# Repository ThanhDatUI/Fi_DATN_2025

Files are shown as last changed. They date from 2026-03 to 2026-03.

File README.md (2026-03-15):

# Thiết Kế Và Phát Triển Mũ Bảo Hiểm IoT  
### Hỗ Trợ Giám Sát An Toàn Giao Thông Và Cảnh Báo Nguy Cơ Tai Nạn
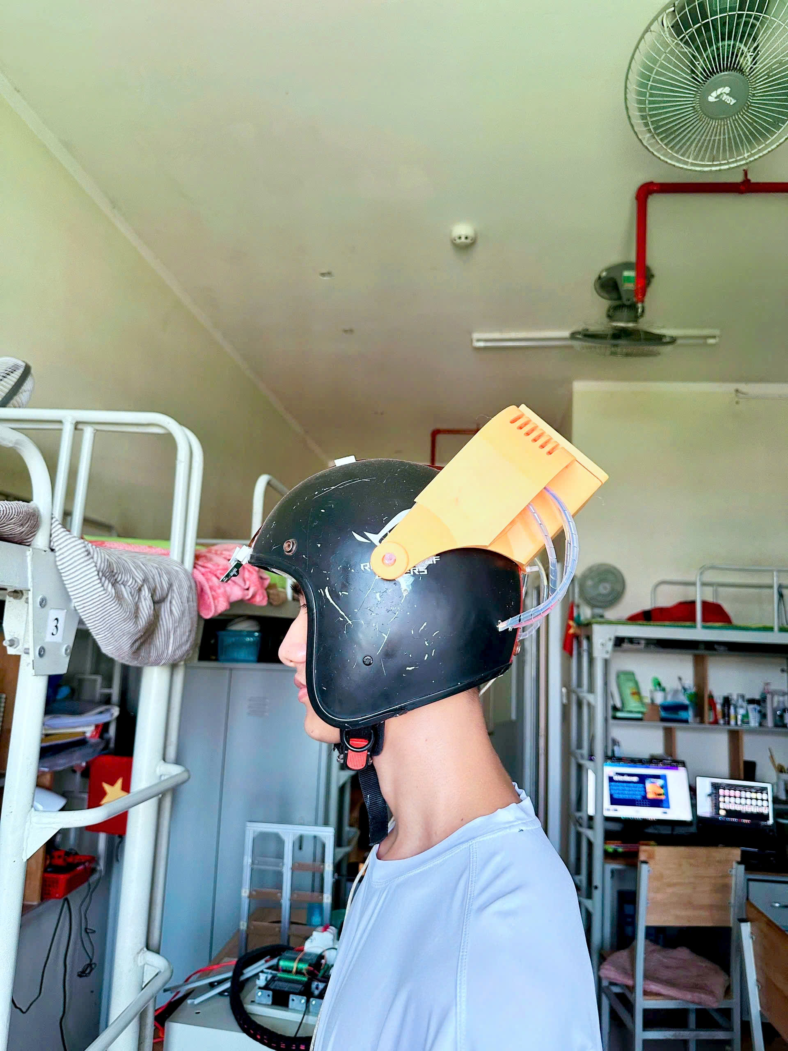
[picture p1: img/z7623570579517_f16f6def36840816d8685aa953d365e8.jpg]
Helmet

## 📌 Giới thiệu
Tai nạn giao thông, đặc biệt liên quan đến xe mô tô, vẫn là vấn đề nghiêm trọng. Nhiều trường hợp xảy ra do người lái không đội mũ bảo hiểm hoặc đội sai cách.  
Đề tài này xây dựng **mũ bảo hiểm thông minh tích hợp IoT và cảm biến hiện đại**, nhằm:
- Giám sát việc đội mũ đúng cách.  
- Phát hiện hành vi nguy hiểm khi lái xe.  
- Cảnh báo và hỗ trợ khẩn cấp trong tình huống tai nạn.  

---

## 🎯 Mục tiêu
- Nhận diện người không đội mũ hoặc đội sai cách bằng **camera + học sâu (MobileNet SSD)**.  
- Phát hiện hành vi nguy hiểm: tăng tốc đột ngột, rung lắc, va chạm.  
- Gửi cảnh báo khẩn cấp qua **SMS, cuộc gọi, email** kèm vị trí GPS.  
- Lưu trữ dữ liệu hành vi lái xe và trạng thái an toàn trên **ứng dụng di động/web**.  

---

## ⚙️ Yêu cầu kỹ thuật
- **Nhận diện hình ảnh**: độ chính xác ≥ 50%, kể cả khi người lái đeo kính hoặc khẩu trang.  
- **Cảm biến lực (FSR402, RFP602)** và **Hall A3144**: kiểm tra việc gài quai, đội mũ đúng cách.  
- **Cảm biến gia tốc MPU6050, SW420, SW520**: phát hiện tăng tốc > 3 m/s², rung lắc, nghiêng bất thường.  
- **GPS NEO6M**: sai số vị trí ±2.5m.  
- **Module SIM900A**: gửi cảnh báo qua mạng di động.  
- **Kết nối IoT**: Raspberry Pi Zero 2W xử lý trung tâm, giao tiếp ESP32 qua UART/MQTT.  
- **Ứng dụng di động/web**: theo dõi trạng thái mũ, lịch sử cảnh báo, vị trí.  

---

## 🛠️ Thiết kế hệ thống
### Phần cứng
- **Camera + Raspberry Pi**: xử lý hình ảnh.  
- **Cảm biến lực, Hall, gia tốc, rung, nghiêng**: giám sát trạng thái mũ và hành vi lái xe.  
- **Module GSM + GPS**: truyền thông và định vị.  
- **Relay + buzzer + LCD**: cảnh báo và điều khiển xe.  

### Phần mềm
- **MobileNet SSD**: nhận diện hình ảnh đội mũ.  
- **Thuật toán giám sát**: phát hiện bất thường, lưu trữ dữ liệu.  
- **Ứng dụng React Native**: giao diện người dùng (Dashboard, Alert History, Location Map, Settings).  

---

## 📊 Kết quả thực nghiệm
- Hệ thống nhận diện đội mũ đạt độ chính xác cao trong nhiều điều kiện ánh sáng.  
- Cảm biến lực và Hall xác định chính xác trạng thái gài quai.  
- Cảm biến gia tốc phát hiện tăng tốc bất thường và va chạm hiệu quả.  
- Ứng dụng di động hiển thị trực quan lịch sử cảnh báo, vị trí và trạng thái mũ.  
- Raspberry Pi Zero 2W vận hành ổn định, CPU & RAM đáp ứng yêu cầu xử lý.  

---

## 🚧 Hạn chế
- Độ chính xác nhận diện hình ảnh còn phụ thuộc vào môi trường ánh sáng.  
- Thời gian phản hồi của hệ thống đôi khi bị ảnh hưởng bởi kết nối mạng.  
- Kích thước và trọng lượng mũ tăng do tích hợp nhiều linh kiện.  

---

## 🔮 Hướng phát triển
- Tối ưu mô hình học sâu để tăng độ chính xác nhận diện.  
- Thu nhỏ kích thước phần cứng, nâng cao tính thẩm mỹ và tiện dụng.  
- Tích hợp thêm tính năng phân tích thói quen lái xe bằng AI.  
- Phát triển hệ thống lưu trữ dữ liệu trên nền tảng **cloud** để mở rộng khả năng giám sát.  

---

## 📚 Tài liệu tham khảo
- Các tài liệu tiếng Việt và tiếng Anh về IoT, học sâu, cảm biến và hệ thống nhúng.  
- Phụ lục: danh sách linh kiện, thông số kỹ thuật, mã nguồn hệ thống.  

---

## 👨‍💻 Tác giả
**Phan Thành Đạt**  
Đồ án tổng hợp – Kỹ thuật Điện tử Viễn thông  
Trường Đại học Tôn Đức Thắng – 2025

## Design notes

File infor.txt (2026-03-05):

THIẾT KẾ VÀ PHÁT TRIỂN MŨ BẢO HIỂM IOT HỖ TRỢ GIÁM SÁT AN TOÀN GIAO THÔNG VÀ CẢNH BÁO NGUY CƠ TAI NẠN
- Tìm hiểu vi điều khiển ESP32, ESP32 CAM hoặc Raspberry Pi, các cảm biến liên quan như cảm biến gia tốc, cảm biến lực, cảm biến va chạm, module gửi nhận tin nhắn.
Tìm hiểu, thiết kế và phát triển mũ bảo hiểm thông minh có các chức năng sau

a. Nhận điện hình ảnh người lái xe không đội mũ bảo hiểm ứng dụng học sâu .
b. Cảm biến lực dùng để phát hiện người đội mũ đúng cách. Nếu phát hiện người đã đội mũ và đội đúng cách thì mới cho phép xe khởi động. Mũ có trang bị khả năng cung cấp âm thanh thông báo khi không đội mũ và đội mũ chưa đúng cách.
c. Mũ cũng được trang bị cảm biến gia tốc hoặc các cảm biến chuyển động khác giúp nhận diện các hành vi nguy hiểm như tăng tốc đột ngột.
d. Trang bị cảm biến va chạm cả trên xe và mũ giúp nhận biết tình huống va chạm và cảnh báo bằng cách gọi điện thoại người thân. Đồng thời gửi định vị GPS giúp xác định vị trí người lái xe.
e. Hệ thống kết nối qua ứng dụng di động hoặc website sử dụng web server ghi lại lịch sử trạng thái, vị trí đội mũ, trạng thái an toàn, ...
Viết chương trình cho vi điều khiển để triển khai thiết kế.

Triển khai mạch phần cứng, thiết kế sản phẩm, kiểm tra và sửa lỗi.

Viết báo cáo theo chuẩn khoa học.

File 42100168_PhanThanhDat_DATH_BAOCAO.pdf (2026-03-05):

TỔNG LIÊN ĐOÀN LAO ĐỘNG VIỆT NAM

TRƯỜNG ĐẠI HỌC TÔN ĐỨC THẮNG

KHOA ĐIỆN – ĐIỆN TỬ

PHAN THÀNH ĐẠT

## THIẾT KẾ VÀ PHÁT TRIỂN MŨ

## BẢO HIỂM IOT HỖ TRỢ GIÁM SÁT

## AN TOÀN GIAO THÔNG VÀ CẢNH

## BÁO NGUY CƠ TAI NẠN

## ĐỒ ÁN TỔNG HỢP KỸ THUẬT ĐIỆN TỬ - VIỄN THÔNG

TP. HỒ CHÍ MINH, NĂM 2025

TỔNG LIÊN ĐOÀN LAO ĐỘNG VIỆT NAM

TRƯỜNG ĐẠI HỌC TÔN ĐỨC THẮNG

KHOA ĐIỆN – ĐIỆN TỬ

PHAN THÀNH ĐẠT - 42100168

## THIẾT KẾ VÀ PHÁT TRIỂN MŨ

## BẢO HIỂM IOT HỖ TRỢ GIÁM SÁT

## AN TOÀN GIAO THÔNG VÀ CẢNH

## BÁO NGUY CƠ TAI NẠN

## ĐỒ ÁN TỔNG HỢP KỸ THUẬT ĐIỆN TỬ - VIỄN THÔNG

Người hướng dẫn
TS. Huỳnh Thanh Thiện

TP. HỒ CHÍ MINH, NĂM 2025

### LỜI CẢM ƠN

Tôi xin chân thành cảm ơn Trường Đại học Tôn Đức Thắng, Khoa Điện - Điện

tử đã tạo điều kiện thuận lợi, cung cấp môi trường học tập chất lượng, giúp tôi tích

lũy kiến thức và phát triển bản thân trong suốt quá trình học tập. Cảm ơn các Thầy

Cô trong Khoa đã luôn tận tâm truyền đạt những kiến thức quý báu, đóng góp to lớn

vào sự trưởng thành của tôi.
Tôi đặc biệt xin gửi lời cảm ơn sâu sắc đến Thầy TS. Huỳnh Thanh Thiện,

Giảng viên hướng dẫn đồ án tổng hợp của tôi. Thầy đã luôn tận tình hỗ trợ, chỉ dạy

và cung cấp những định hướng chính xác giúp tôi hoàn thành tốt đồ án này. Sự quan

tâm và hướng dẫn của Thầy là nguồn động lực lớn lao trong suốt quá trình nghiên

cứu và thực hiện đồ án.

Tôi cũng xin gửi lời cảm ơn đến các thành viên trong Hội đồng bảo vệ đồ án,

những người đã dành thời gian quý báu để lắng nghe, đánh giá và đưa ra những nhận

xét bổ ích giúp tôi hoàn thiện đồ án tốt nghiệp của mình.

Cuối cùng, tôi xin chân thành cảm ơn gia đình, bạn bè và những người thân

yêu đã luôn đồng hành, động viên và hỗ trợ tôi vượt qua mọi khó khăn trong suốt thời

gian học tập. Sự hy sinh và tình cảm của họ là yếu tố không thể thiếu giúp tôi hoàn

thành đồ án này.

TP. Hồ Chí Minh, ngày 09 tháng 07 năm 2025

Tác giả

Phan Thành Đạt

Công trình được hoàn thành tại Trường Đại học Tôn Đức Thắng

Cán bộ hướng dẫn khoa học: |

(Ghi rõ học hàm, học vị, họ tên và chữ ký)

Đồ án tổng hợp được bảo vệ tại Hội đồng đánh giá Đồ án tổng hợp của Trường

Đại học Tôn Đức Thắng vào ngày… /…/……

Xác nhận của Chủ tịch Hội đồng đánh giá Đồ án tốt nghiệp/tổng hợp và Trưởng khoa quản lý chuyên ngành sau khi nhận Đồ án tốt nghiệp/tổng hợp đã được sửa chữa (nếu có).

CHỦ TỊCH HỘI ĐỒNG | TRƯỞNG KHOA

### CÔNG TRÌNH ĐƯỢC HOÀN THÀNH

### TẠI TRƯỜNG ĐẠI HỌC TÔN ĐỨC THẮNG

Tôi xin cam đoan đây là công trình nghiên cứu của riêng tôi và được sự hướng dẫn khoa học của TS. Huỳnh Thanh Thiện. Các nội dung nghiên cứu, kết quả trong

đề tài này là trung thực và chưa công bố dưới bất kỳ hình thức nào trước đây. Những

số liệu trong các bảng biểu phục vụ cho việc phân tích, nhận xét, đánh giá được chính

tác giả thu thập từ các nguồn khác nhau có ghi rõ trong phần tài liệu tham khảo.

Ngoài ra, trong Đồ án tổng hợp còn sử dụng một số nhận xét, đánh giá cũng

như số liệu của các tác giả khác, cơ quan tổ chức khác đều có trích dẫn và chú thích

nguồn gốc.

Nếu phát hiện có bất kỳ sự gian lận nào tôi xin hoàn toàn chịu trách nhiệm

về nội dung Đồ án tổng hợp của mình. Trường Đại học Tôn Đức Thắng không liên

quan đến những vi phạm tác quyền, bản quyền do tôi gây ra trong quá trình thực hiện.

TP. Hồ Chí Minh, ngày 09 tháng 07 năm 2025

Tác giả

Phan Thành Đạt

### THIẾT KẾ VÀ PHÁT TRIỂN MŨ BẢO HIỂM IOT HỖ TRỢ

### GIÁM SÁT AN TOÀN GIAO THÔNG VÀ

### CẢNH BÁO NGUY CƠ TAI NẠN

### TÓM TẮT

An toàn giao thông là một yếu tố quan trọng trong việc giảm thiểu tai nạn và

bảo vệ người tham gia giao thông. Mặc dù nhiều biện pháp an toàn đã được triển khai,

nhưng việc đảm bảo người lái xe tuân thủ các quy định về đội mũ bảo hiểm vẫn còn

là một thách thức lớn. Trong bối cảnh đó, mũ bảo hiểm thông minh tích hợp công

nghệ IoT và các cảm biến hiện đại hứa hẹn sẽ là một giải pháp đột phá trong việc

giám sát an toàn giao thông.
Đề tài này trình bày quy trình thiết kế và phát triển mũ bảo hiểm thông minh,

được trang bị các cảm biến để giám sát việc đội mũ của người lái xe và phát hiện các

hành vi nguy hiểm trong quá trình di chuyển. Mũ bảo hiểm sử dụng công nghệ học

sâu để nhận diện và cảnh báo khi người lái xe không đội mũ bảo hiểm hoặc đội mũ

sai cách. Bên cạnh đó, các cảm biến gia tốc và va chạm được tích hợp để phát hiện

các tình huống nguy hiểm như tăng tốc đột ngột hoặc va chạm, từ đó cung cấp cảnh

báo khẩn cấp ngay lập tức.

Mô hình mũ bảo hiểm này cũng có khả năng kết nối với ứng dụng di động

hoặc nền tảng web, cho phép người dùng theo dõi tình trạng an toàn giao thông trong

thời gian thực và nhận thông tin liên quan đến các hành vi lái xe và nguy cơ tai nạn.

Hệ thống không chỉ giúp nâng cao ý thức tuân thủ các quy định về an toàn giao thông

mà còn đóng góp tích cực vào việc giảm thiểu số lượng tai nạn và cải thiện chất lượng

cuộc sống cho người tham gia giao thông.

### DESIGN AND DEVELOPMENT OF AN IOT HELMET

### FOR TRAFFIC SAFETY MONITORING AND

### ACCIDENT RISK WARNING

### ABSTRACT

Traffic safety plays a crucial role in reducing accidents and protecting road

users. Despite the implementation of various safety measures, ensuring that drivers

comply with helmet regulations remains a major challenge. In this context, smart

helmets integrated with IoT technology and advanced sensors offer a promising

solution for enhancing traffic safety monitoring.

This study presents the design and development process of a smart helmet

equipped with sensors to monitor helmet usage and detect risky behaviors while

driving. The helmet employs deep learning techniques to identify and issue alerts

when the rider is not wearing a helmet or wearing it incorrectly. In addition, integrated

accelerometer and collision sensors enable the detection of dangerous situations such

as sudden acceleration or impact, thereby providing instant emergency warnings.

The smart helmet prototype can also connect to a mobile application or web

platform, allowing users to monitor traffic safety conditions in real time and access

information regarding driving behaviors and accident risks. The proposed system not

only raises awareness of compliance with traffic safety regulations but also

contributes to reducing accident rates and improving the quality of life for road users.

### MỤC LỤC

CHƯƠNG 3. THIẾT KẾ VÀ PHÁT TRIỂN MŨ BẢO HIỂM IOT HỖ TRỢ

GIÁM SÁT AN TOÀN GIAO THÔNG VÀ CẢNH BÁO NGUY CƠ TAI NẠN

Tiếng Anh | 54
PHỤ LỤC | 1
Phụ lục A: Danh sách linh kiện sử dụng | A-1
A.1 Danh sách linh kiện sử dụng | A-1
A.2 Thông số kỹ thuật các cảm biến chính | A-2
Phụ lục B: Mã nguồn phát triển | B-1
B.1 Mã nguồn hệ thống 1 | B-1
B.2 Mã nguồn hệ thống 2 | B-15

### DANH MỤC HÌNH VẼ

Hình 3-12 Learning Curve của quá trình huấn luyện mô hình MobileNet SSD

Hình 4-9 Hiệu suất hoạt động của CPU&RAM của Raspberry Pi Zero 2W....49

### DANH MỤC BẢNG BIỂU

Bảng 3-1 Công suất tiêu ước tính của hệ thống | 22
Bảng 3-2 Tóm tắt giao thức giao tiếp | 29
Bảng 4-1 Hiệu suất quan sát được của hệ thống | 47
Bảng A.1 Danh sách linh kiện sử dụng trong mô hình | 1

Bảng A.2 Thông số kỹ thuật chính của các linh kiện sử dụng trong hệ thống....2

Bảng A.3 Thông số kỹ thuật ESP32 DevKit V1 | 3
Bảng A.4 Thông số kỹ thuật Raspberry Pi Zero 2W | 4

### DANH MỤC CÁC CHỮ VIẾT TẮT

ADC | Analog to Digital Converter
AI | Artificial Intelligence
API | Application Programming Interface
CNN | Convolutional Neural Network
CPU | Central Processing Unit
ESP32 | Embedded Serial Processor 32-bit
FP | False Positive
FN | False Negative
FPS | Frames Per Second
FSR | Force Sensitive Resistor
GPS | Global Positioning System
GSM | Global System for Mobile Communications
HTTP | HyperText Transfer Protocol
I2C | Inter-Integrated Circuit
IoT | Internet of Things
LCD | Liquid Crystal Display
LED | Light Emitting Diode
MQTT | Message Queuing Telemetry Transport
OTA | Over-The-Air
RAM | Random Access Memory
REST | Representational State Transfer
SSD | Single Shot Multibox Detector
SMS | Short Message Service
TP | True Positive
TN | True Negative
UART | Universal Asynchronous Receiver Transmitter
Wi-Fi | Wireless Fideli

ĐỒ ÁN TỔNG HỢP
Trang 1

Thiết kế và phát triển mũ bảo hiểm IoT hỗ trợ giám sát an toàn giao thông và cảnh báo nguy cơ tai nạn

CHƯƠNG 1. GIỚI THIỆU ĐỀ TÀI

### 1.1 Mục đích thực hiện đề tài

Mục đích của việc thiết kế và phát triển mũ bảo hiểm IoT hỗ trợ giám sát an

toàn giao thông và cảnh báo nguy cơ tai nạn là xây dựng một hệ thống mũ bảo hiểm

thông minh, tích hợp công nghệ Internet of Things (IoT), nhằm nâng cao an toàn giao

thông và giảm thiểu nguy cơ tai nạn cho người tham gia giao thông. Tai nạn giao

thông, đặc biệt là tai nạn liên quan đến người lái xe mô tô, vẫn là vấn đề nghiêm trọng

và phổ biến, với nhiều vụ tai nạn do người lái xe không đội mũ bảo hiểm hoặc đội sai

cách.
Đề tài này nhằm phát triển một hệ thống mũ bảo hiểm thông minh, tích hợp

các cảm biến và thuật toán học sâu để giám sát việc đội mũ của người lái xe. Hệ thống

này sẽ nhận diện người không đội mũ bảo hiểm và cảnh báo khi mũ đội không đúng

cách, góp phần nâng cao nhận thức của người lái xe và thúc đẩy việc tuân thủ các quy

định về an toàn giao thông. Đồng thời, mũ bảo hiểm còn được trang bị cảm biến gia

tốc và cảm biến va chạm để phát hiện những hành vi nguy hiểm như tăng tốc đột

ngột, giảm tốc nhanh hoặc va chạm. Khi xảy ra tai nạn hoặc tình huống nguy hiểm,

hệ thống sẽ tự động gửi thông báo khẩn cấp đến người thân hoặc cơ quan chức năng

đã được thiết lập trước đó, đồng thời cung cấp thông tin định vị để hỗ trợ nhanh chóng

trong việc cứu hộ.
Mục tiêu của đề tài không chỉ là phát triển một giải pháp công nghệ để nâng

cao an toàn giao thông mà còn nhằm thay đổi nhận thức cộng đồng về tầm quan trọng

của việc tuân thủ các quy định an toàn. Hệ thống mũ bảo hiểm thông minh này sẽ

giúp người lái xe không chỉ bảo vệ bản thân mà còn góp phần giảm thiểu tai nạn giao

thông, bảo vệ tính mạng và sức khỏe cho cộng đồng. Thêm vào đó, qua việc ứng dụng

công nghệ IoT và các cảm biến thông minh, hệ thống này sẽ mở ra những cơ hội phát

triển thêm các ứng dụng liên quan trong tương lai.

Trang 2

Thiết kế và phát triển mũ bảo hiểm IoT hỗ trợ giám sát an toàn giao thông và cảnh

### 1.2 Yêu cầu kỹ thuật

Đề tài yêu cầu thiết kế và phát triển mô hình mũ bảo hiểm IoT hỗ trợ giám sát

an toàn giao thông và cảnh báo nguy cơ tai nạn như một công cụ điều chỉnh hành vi

của người tham gia giao thông, nhằm đảm bảo sự tuân thủ các quy định an toàn và

giảm thiểu rủi ro tai nạn. Cụ thể, người thực hiện cần phát triển mũ bảo hiểm với các

yêu cầu sau:

Mô hình mũ bảo hiểm IoT cần được thiết kế với khả năng nhận diện hình ảnh

người lái xe không đội mũ bảo hiểm thông qua ứng dụng học sâu. Hệ thống phải dùng

mô hình học sâu (deep learning) để phân tích và nhận diện hình ảnh từ camera gắn

trên mũ, nhằm xác định người lái xe có đội mũ bảo hiểm hay không. Cụ thể, khi người

lái xe đội mũ bảo hiểm, hệ thống sẽ nhận diện hình ảnh khuôn mặt của người lái xe

xuất hiện trong vùng quan sát của camera gắn trên mũ bảo hiểm với độ chính xác

nhận diện khuôn mặt từ 50% trở lên và phải đảm bảo tính chính xác trong các tính huống người đội mũ trang bị kính mắt hoặc khẩu trang.

Mũ bảo hiểm cần phải tích hợp cảm biến lực hoặc các cảm biến khác để phát

hiện người đội mũ đúng cách. Cảm biến này đo lường lực tác động lên mũ khi người

lái xe đội hoặc xác nhận xem người sử dụng mũ đã gài quai an toàn hay chưa, từ đó xác định xem mũ có được đội đúng cách và đúng vị trí hay không. Nếu mũ được đội

chắc chắn và đúng cách, lực phân bổ sẽ ổn định trên các điểm tiếp xúc giữa mũ và

đầu người lái. Ngược lại, nếu mũ bị lệch hoặc không ôm sát đầu, hệ thống sẽ không

cho phép xe khởi động, đảm bảo an toàn cho người lái. Đồng thời, mũ bảo hiểm phải

được trang bị khả năng phát âm thanh thông báo khi người lái xe không đội mũ hoặc đội mũ chưa đúng cách. Cụ thể, khi hệ thống nhận biết trạng thái đội mũ của người

lái xe chưa phù hợp, như mũ bị lệch hoặc không gài quai đúng cách, hệ thống sẽ phát

ra âm thanh cảnh báo để người lái xe điều chỉnh lại mũ bảo hiểm trước khi có thể

khởi động xe, giúp đảm bảo an toàn và nâng cao ý thức chấp hành các quy định an

toàn giao thông.
Mũ bảo hiểm cần được trang bị cảm biến gia tốc và các cảm biến chuyển động

khác để nhận diện các hành vi nguy hiểm của người lái xe, như tăng tốc đột ngột. Khi

Trang 3

Thiết kế và phát triển mũ bảo hiểm IoT hỗ trợ giám sát an toàn giao thông và cảnh hệ thống phát hiện người lái xe tăng tốc quá nhanh, ví dụ như gia tốc vượt quá 3m/s²

hoặc có thay đổi vận tốc bất thường, hệ thống sẽ phát ra cảnh báo âm thanh trực tiếp

trên mũ bảo hiểm hoặc gửi thông báo qua ứng dụng di động. Đồng thời, hệ thống khi

thiết kết sẽ phải lưu trữ các dữ liệu về hành vi lái xe nguy hiểm, bao gồm thông tin

về các lần tăng tốc đột ngột và các tình huống vi phạm, để giúp cải thiện nhận thức

và hành vi lái xe trong tương lai.
Mũ bảo hiểm và xe sẽ cần phải được trang bị cảm biến va chạm để nhận biết

các tình huống va chạm trong quá trình di chuyển. Khi hệ thống phát hiện va chạm,

cảm biến trên mũ bảo hiểm và xe sẽ xác định vị trí và mức độ nghiêm trọng của vụ

va chạm thông qua sự thay đổi về lực tác động. Ngay lập tức, hệ thống sẽ phát ra cảnh

báo khẩn cấp và tự động gọi điện thoại cho người thân của người lái xe để thông báo

về tình huống tai nạn. Đồng thời, mô hình mũ bảo hiểm này sẽ cần sử dụng GPS với

độ chính xác vị trí ±2.5 mét để xác định chính xác vị trí của người lái xe và gửi thông

tin này đến người thân hoặc các cơ quan cứu hộ.

Hệ thống mũ bảo hiểm thông minh này sẽ phải phát triển để kết nối với ứng

dụng di động hoặc website thông qua một web server để ghi lại và theo dõi các thông

tin liên quan đến người lái xe. Mỗi khi người lái xe sử dụng mũ bảo hiểm, hệ thống

sẽ tự động ghi nhận và lưu trữ lịch sử trạng thái đội mũ, bao gồm thông tin về việc

mũ có được đội đúng cách hay không, thời gian sử dụng và các hành vi nguy hiểm.

Ngoài ra, trạng thái an toàn của người lái xe cũng phải được theo dõi liên tục, với thông tin về các cảnh báo, va chạm hoặc tình huống nguy hiểm, giúp tạo ra một hồ

sơ an toàn chi tiết. Tất cả dữ liệu này phải được lưu trữ trên thông qua ứng dụng di

động hoặc web server, cho phép người dùng truy cập dễ dàng thông qua ứng dụng di

động hoặc website để xem lại lịch sử, phân tích các hành vi lái xe và đánh giá mức

độ an toàn của mỗi chuyến đi.

### 1.3 Ý tưởng và phương pháp thực hiện

Dự án được xây dựng với mục tiêu phát triển một mô hình mũ bảo hiểm thông

minh có khả năng giám sát an toàn giao thông và hỗ trợ xử lý tình huống khẩn cấp,

Trang 4

Thiết kế và phát triển mũ bảo hiểm IoT hỗ trợ giám sát an toàn giao thông và cảnh hướng đến việc nâng cao ý thức và hành vi của người điều khiển phương tiện. Ý

tưởng cốt lõi là thiết kế một thiết bị tích hợp các công nghệ hiện đại như xử lý ảnh,

cảm biến và truyền thông không dây trong một hệ thống hoàn chỉnh. Hệ thống sử

dụng camera kết hợp với thuật toán học sâu MobileNet SSD (Single Shot Multibox

Detector) để nhận diện người đội mũ bảo hiểm một cách chính xác ngay cả trong môi

trường thiếu ánh sáng. Ngoài ra, các cảm biến lực như FSR402 và RFP602 cùng với

cảm biến từ trường Hall A3144 được tích hợp để kiểm tra việc đội mũ đúng cách và

xác nhận người dùng đã gài quai an toàn. Sau khi xác nhận đầy đủ các điều kiện an

toàn, Raspberry Pi sẽ đóng vai trò xử lý trung tâm, gửi tín hiệu điều khiển không dây

đến vi điều khiển ESP32 để kích hoạt relay, cho phép xe được khởi động.

Không dừng lại ở chức năng nhận diện và cho phép khởi động xe, hệ thống

còn được trang bị các cảm biến như MPU6050 (gia tốc kế và con quay hồi chuyển),

SW420 (cảm biến rung) và SW520 (cảm biến nghiêng) nhằm nhận biết các hành vi

nguy hiểm như tăng tốc đột ngột, rung lắc mạnh hoặc va chạm bất thường. Mỗi khi

xảy ra tình huống có dấu hiệu tai nạn, hệ thống sẽ kích hoạt cơ chế cảnh báo thông

minh: sử dụng module GPS để xác định vị trí người điều khiển và module SIM để

gửi tin nhắn hoặc tự động gọi điện thoại đến người thân hoặc cơ quan chức năng cứu

hộ. Trong trường hợp tin nhắn hoặc cuộc gọi không thể thực hiện do mất sóng hoặc

sự cố mạng, hệ thống còn được tích hợp chức năng gửi email khẩn cấp kèm theo

thông tin định vị và thời điểm xảy ra sự cố đến các địa chỉ liên hệ được thiết lập trước

nhằm đảm bảo cảnh báo luôn được gửi đi kịp thời. Bên cạnh đó, toàn bộ dữ liệu về

hành vi lái xe, trạng thái an toàn và lịch sử sử dụng thiết bị sẽ được lưu trữ một cách

có hệ thống, cho phép người dùng truy cập thông qua ứng dụng di động hoặc website.

Hệ thống còn cung cấp các báo cáo phân tích chi tiết về thói quen điều khiển phương

tiện, hỗ trợ người dùng điều chỉnh hành vi không an toàn và nâng cao ý thức khi tham

gia giao thông. Với khả năng tích hợp linh hoạt, độ chính xác cao và giao diện thân thiện, mô hình mũ bảo hiểm IoT này hứa hẹn sẽ là một giải pháp hữu ích trong việc

giảm thiểu rủi ro tai nạn giao thông và bảo vệ tính mạng người điều khiển phương

tiện.

Trang 5

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

CHƯƠNG 2. CƠ SỞ LÝ THUYẾT

### 2.1 Tổng quan về mũ bảo hiểm thông minh và IoT

Mũ bảo hiểm thông minh là một thiết bị bảo hộ được tích hợp thêm các thành

phần điện tử và kết nối mạng, nhằm hỗ trợ người dùng nâng cao mức độ an toàn khi

tham gia giao thông. Khác với mũ bảo hiểm truyền thống chỉ có chức năng bảo vệ cơ

học, mũ thông minh có khả năng giám sát trạng thái đội mũ, phát hiện hành vi nguy hiểm và cảnh báo kịp thời khi xảy ra sự cố. Trong hệ thống được đề xuất, các tính

năng chính bao gồm: nhận diện người đội mũ bằng hình ảnh từ camera, phát hiện tình

trạng gài quai thông qua cảm biến từ trường, xác định va chạm và chuyển động bất

thường nhờ cảm biến gia tốc, cảm biến nghiêng và chuyển động. Ngoài ra, hệ thống

còn có thể kết nối với module GPS và SIM để gửi vị trí và cảnh báo khẩn cấp đến

người thân trong trường hợp xảy ra tai nạn.
IoT đóng vai trò là nền tảng kết nối giữa các thiết bị cảm biến, vi xử lý và phần

mềm. Dữ liệu thu thập được từ các cảm biến và camera được truyền về bộ xử lý trung

tâm (Raspberry Pi) để phân tích, xử lý và đưa ra quyết định điều khiển như bật relay

khởi động, phát âm thanh cảnh báo hoặc gửi dữ liệu lên ứng dụng di động. Sự kết

hợp giữa mũ bảo hiểm thông minh và nền tảng IoT giúp hệ thống hoạt động linh hoạt,

đồng thời hỗ trợ lưu trữ, thống kê và giám sát hành vi người điều khiển một cách hiệu

quả theo thời gian thực.

### 2.2 Ứng dụng học sâu trong nhận diện hình ảnh

Học sâu (Deep Learning) là một lĩnh vực trong trí tuệ nhân tạo, mô phỏng cách hoạt động của não bộ con người để xử lý và phân tích dữ liệu đầu vào có cấu trúc

phức tạp, đặc biệt là hình ảnh. Trong hệ thống mũ bảo hiểm thông minh, học sâu được

sử dụng để nhận diện khuôn mặt người điều khiển phương tiện, qua đó xác định tình

trạng đội mũ (có đội, không đội). Điều này được thực hiện thông qua camera tích hợp

và một mô hình học sâu đã được huấn luyện trước.

Trang 6

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

Hai kiến trúc học sâu được sử dụng phổ biến trong bài toán nhận diện hình ảnh

là CNN (Convolutional Neural Network) và YOLO (You Only Look Once). CNN hoạt động bằng cách sử dụng các lớp tích chập để tự động trích xuất đặc trưng từ hình

ảnh đầu vào. Các lớp chính trong CNN bao gồm: lớp tích chập (convolutional layer),

lớp kích hoạt (activation layer), lớp gộp (pooling layer) và lớp kết nối đầy đủ (fully

connected layer). Đây là mô hình hiệu quả cho phân loại và phân đoạn ảnh.
Trong khi đó, YOLO là mô hình nhận diện đối tượng theo thời gian thực. Ưu

điểm lớn nhất của YOLO là khả năng phát hiện nhiều đối tượng trong một lần xử lý

duy nhất, giúp tối ưu tốc độ xử lý. YOLO hoạt động bằng cách chia ảnh đầu vào thành

các ô lưới và dự đoán bounding box cùng với class probability cho mỗi ô, từ đó xác

định vị trí và nhãn của đối tượng.

Hệ thống sử dụng mô hình MobileNet SSD, kết hợp kiến trúc MobileNet để

giảm số tham số với SSD giúp phát hiện nhanh các đối tượng. Mô hình này được triển

khai dưới định dạng TensorFlow Lite giúp chạy tốt trên thiết bị nhúng như Raspberry

Pi Zero 2W. Ảnh đầu vào sẽ được resize về kích thước 300x300 pixel, sau đó thực

hiện suy luận để xác định các bounding box, class ID và confidence score của các đối

tượng. Chỉ các đối tượng có độ tin cậy trên 50% mới được giữ lại để phân tích.

### 2.3 Đánh giá mô hình học sâu trong nhận diện ảnh

Trong hệ thống mũ bảo hiểm thông minh, việc sử dụng mô hình học sâu là yếu

tố cốt lõi để nhận diện hình ảnh khuôn mặt người điều khiển và đánh giá trạng thái

đội mũ. Do đó, việc đánh giá hiệu quả của mô hình học sâu là cần thiết để đảm bảo

tính chính xác và độ tin cậy trong điều kiện thực tế. Các tiêu chí quan trọng thường

được sử dụng để đánh giá bao gồm độ chính xác (accuracy), tốc độ xử lý (inference

time hoặc FPS – frames per second) và khả năng tổng quát (generalization). Độ chính

xác phản ánh tỷ lệ nhận diện đúng các đối tượng trong ảnh đầu vào so với tổng số dự

đoán. Tuy nhiên, trong bài toán nhận diện đối tượng cụ thể như phát hiện khuôn mặt

hay khẩu trang, kính mắt, các chỉ số như Precision, Recall và đặc biệt là chỉ số mAP

(mean Average Precision) được sử dụng để đánh giá chi tiết hơn.

Trang 7

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

Chỉ số mAP được tính bằng trung bình của các giá trị AP (Average Precision) theo

từng lớp đối tượng, được định nghĩa bởi công thức:

1

1

N

i
i
mAP | AP
N =

= ∑
(2.1)

Trong đó N là số lượng các lớp đối tượng (ví dụ: mũ bảo hiểm, người lái xe, v.v.) và

APi

là Average Precision cho lớp đối tượng thứ i. Việc sử dụng mAP giúp mô tả đầy

đủ mức độ chính xác trong việc phát hiện và phân loại đối tượng của mô hình học

sâu.

Bên cạnh độ chính xác, tốc độ xử lý cũng là yếu tố quan trọng trong hệ thống

thời gian thực. Mô hình cần đạt tối thiểu 15–30 FPS để có thể phát hiện và đưa ra

cảnh báo kịp thời. Trong hệ thống này, mô hình MobileNet SSD được sử dụng vì có

kiến trúc gọn nhẹ, xử lý nhanh và tiêu thụ ít tài nguyên, phù hợp cho các thiết bị

nhúng như Raspberry Pi Zero 2W. Cuối cùng, khả năng tổng quát của mô hình cần

được kiểm tra để đảm bảo mô hình vẫn hoạt động hiệu quả trên các hình ảnh có điều

kiện ánh sáng, góc nhìn hoặc môi trường khác với dữ liệu huấn luyện. Phương pháp

kiểm tra chéo (cross-validation) hoặc sử dụng tập kiểm tra độc lập (hold-out test set)

thường được áp dụng để đánh giá yếu tố này.

### 2.4 Đánh giá thuật toán học máy trong phân tích dữ liệu

Thuật toán học máy là công cụ quan trọng trong phân tích dữ liệu, giúp khai thác thông tin, nhận diện mẫu và đưa ra dự đoán từ dữ liệu thô. Hệ thống mũ bảo

hiểm thông minh không chỉ phụ thuộc vào khả năng nhận diện hình ảnh, mà còn dựa

vào các cảm biến như gia tốc, va chạm, rung động và góc nghiêng để thu thập dữ liệu

số, phục vụ cho quá trình phân tích hành vi và đánh giá mức độ an toàn của người

điều khiển. Việc đánh giá các thuật toán học máy được ứng dụng trong quá trình này

là cần thiết nhằm đảm bảo rằng hệ thống phản hồi đúng và chính xác trong việc phát

hiện hành vi nguy hiểm hoặc tình huống bất thường.

Với các mô hình học có giám sát, chỉ số accuracy là một trong những tiêu chí

đánh giá phổ biến. Chỉ số này được tính dựa trên bốn thành phần chính: TP (True

Trang 8

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

Positive – dự đoán đúng dương tính), TN (True Negative – dự đoán đúng âm tính),

FP (False Positive – dự đoán sai dương tính), và FN (False Negative – dự đoán sai

âm tính). Công thức tính như sau:

TP TN Accuracy
TP TN FP FN

+
=
+ | + | +

(2.2)

Chỉ số này cho biết mô hình đã đưa ra bao nhiêu dự đoán đúng so với tổng số dự

đoán. Trong một số trường hợp, khi dữ liệu mất cân bằng (ví dụ số trường hợp có va

chạm ít hơn nhiều so với không có va chạm), thì các chỉ số Precision, Recall hoặc F1-

score sẽ được ưu tiên hơn để đánh giá hiệu quả mô hình.

Mô hình học có giám sát được đánh giá hiệu quả khi có khả năng phân loại đúng phần lớn các tình huống thực tế. Tuy nhiên, trong trường hợp dữ liệu mất cân

bằng, chẳng hạn như số lượng mẫu “không có va chạm” lớn hơn nhiều so với “có va

chạm” thì chỉ số Accuracy có thể gây hiểu nhầm về hiệu suất. Khi đó, cần kết hợp

thêm các chỉ số như Precision và Recall để đánh giá khả năng phát hiện đúng tình

huống nguy hiểm và giảm thiểu cảnh báo sai.

Bên cạnh độ chính xác, mô hình cũng cần đảm bảo khả năng tổng quát, tức

là khả năng áp dụng hiệu quả trên dữ liệu mới chưa từng gặp. Mô hình tổng quát tốt

sẽ giữ được hiệu suất cao trong điều kiện thực tế, nơi dữ liệu có thể thay đổi theo môi

trường và hành vi người dùng. Để kiểm tra, các phương pháp như cross-validation

hoặc hold-out validation thường được áp dụng nhằm đánh giá độ tin cậy của mô hình

trên các bộ dữ liệu kiểm thử độc lập, tránh hiện tượng quá khớp với dữ liệu huấn

luyện (overfitting).

Trang 9

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

CHƯƠNG 3. THIẾT KẾ VÀ PHÁT TRIỂN MŨ BẢO HIỂM IOT HỖ TRỢ GIÁM SÁT AN TOÀN GIAO THÔNG VÀ CẢNH BÁO NGUY CƠ TAI NẠN

### 3.1 Mô hình hệ thống tổng thể

### 3.1.1 Mục tiêu kỹ thuật và kiến trúc tổng thể

Hệ thống mũ bảo hiểm thông minh tích hợp công nghệ IoT được thiết kế nhằm

đáp ứng các mục tiêu kỹ thuật trọng yếu: đảm bảo khả năng giám sát an toàn cho

người điều khiển phương tiện trong thời gian thực; phát hiện nhanh và chính xác các

tình huống nguy hiểm; cung cấp cảnh báo kịp thời; đồng thời duy trì hiệu năng ổn

định trên nền tảng phần cứng nhúng có tài nguyên hạn chế như Raspberry Pi Zero

2W và vi điều khiển ESP32.

Trước hết, hệ thống phải đảm bảo khả năng nhận diện chính xác trạng thái đội

mũ của người lái xe. Thông qua camera tích hợp và thuật toán học sâu MobileNet SSD, hệ thống có thể xác định xem người dùng có đội mũ bảo hiểm hay không, kể cả

trong các trường hợp người điều khiển đeo khẩu trang hoặc kính mắt. Bên cạnh đó,

các cảm biến lực được bố trí bên trong mũ cho phép phát hiện xem mũ có được đội

đúng cách, ôm sát đầu người dùng hay không. Chức năng này giúp ngăn chặn trường

hợp người dùng chỉ treo mũ hoặc đội không đúng cách để qua mặt hệ thống.

Song song với đó, hệ thống còn có nhiệm vụ phát hiện các hành vi nguy hiểm

trong quá trình vận hành phương tiện. Dữ liệu thu thập từ cảm biến gia tốc MPU6050,

cảm biến rung SW420 và cảm biến nghiêng SW520 được phân tích theo thời gian

thực nhằm nhận diện các tình huống như tăng tốc đột ngột, va chạm, hoặc té ngã. Khi

phát hiện sự kiện bất thường, hệ thống sẽ lập tức kích hoạt cảnh báo bằng loa buzzer,

đồng thời gửi thông báo và thông tin vị trí thông qua module SIM900A và GPS NEO-

6M đến các số điện thoại khẩn cấp đã được cài đặt trước.

Trang 10

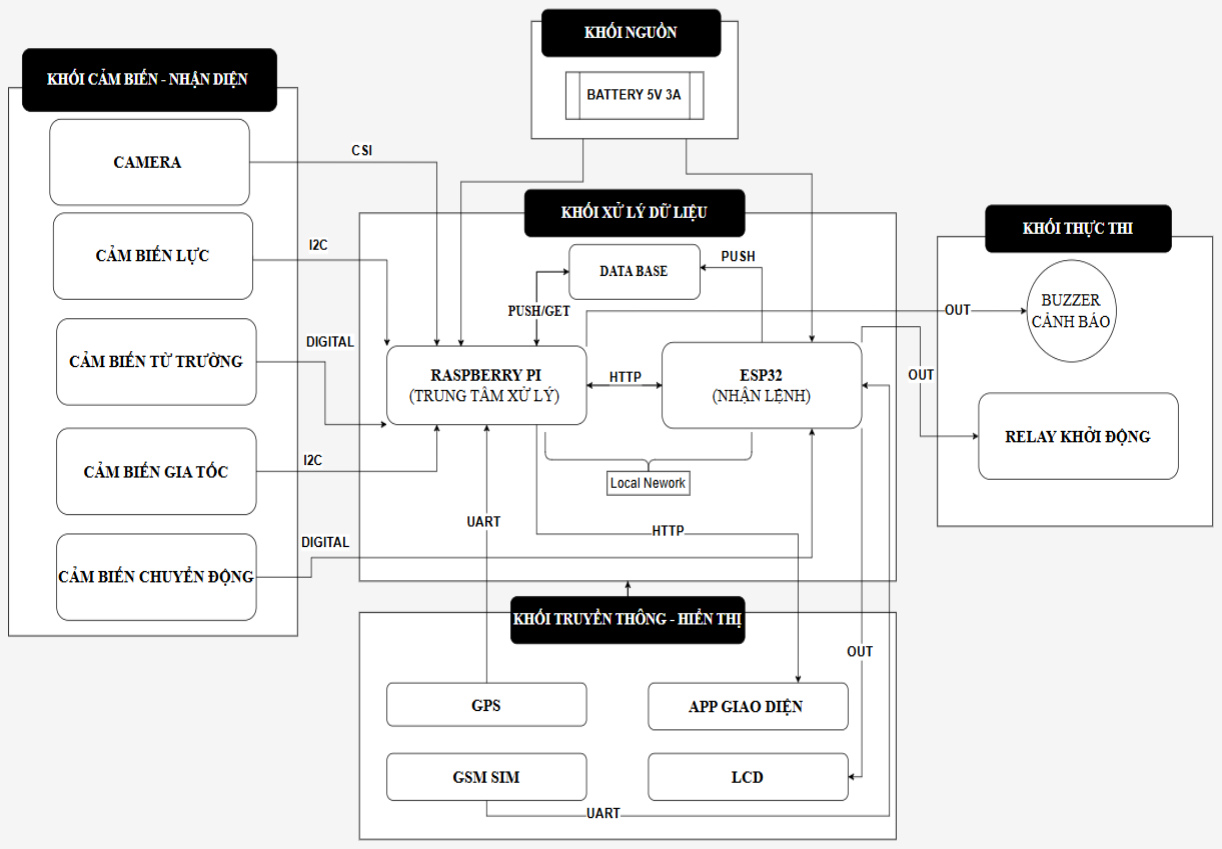
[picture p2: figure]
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

Về mặt kiến trúc, hệ thống được tổ chức thành ba lớp chức năng chính. Lớp

đầu tiên là lớp thu thập dữ liệu, bao gồm camera và các cảm biến vật lý (FSR, Hall,

MPU6050, SW420, SW520). Lớp thứ hai là lớp xử lý và điều khiển trung tâm, sử

dụng Raspberry Pi Zero 2W làm bộ xử lý chính, kết hợp với vi điều khiển ESP32

đóng vai trò chấp hành phần cứng (bật/tắt relay khởi động xe, phát cảnh báo). Lớp

thứ ba là lớp truyền thông và phản hồi khẩn cấp, với các module GPS, GSM và giao

diện ứng dụng di động cho phép theo dõi và giám sát tình trạng an toàn từ xa.
Hệ thống áp dụng mô hình giao tiếp phân tầng giữa Raspberry Pi và ESP32,

sử dụng giao thức HTTP REST API trên mạng Wi-Fi cục bộ. Cách tiếp cận này không

chỉ đảm bảo tính tương thích cao giữa các thiết bị mà còn giúp giảm độ trễ truyền

thông, tăng khả năng mở rộng và dễ bảo trì về sau. Ngoài ra, các dữ liệu về trạng thái

vận hành và lịch sử cảnh báo cũng được đồng bộ hóa với dịch vụ Google Sheets nhằm

hỗ trợ lưu trữ lâu dài và phục vụ phân tích hành vi người dùng.

### 3.1.2 Sơ đồ khối hệ thống

Hình 3-1 Sơ đồ khối hệ thống

Trang 11

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

Sơ đồ khối tổng thể của hệ thống mũ bảo hiểm thông minh dùng để giám sát

và cảnh báo tai nạn được tích hợp IoT trong hệ thống được thể hiện trong Hình 3-1.

Hệ thống trên được chia thành năm khối chức năng chính: khối cảm biến – nhận diện,

khối xử lý dữ liệu, khối thực thi, khối truyền thông – hiển thị và khối nguồn. Các khối

được kết nối với nhau thông qua các chuẩn giao tiếp phổ biến như CSI, I2C, UART,

digital GPIO và HTTP nội bộ.
Khối cảm biến – nhận diện bao gồm camera, cảm biến lực (FSR và RFP), cảm

biến từ trường (Hall), cảm biến gia tốc (MPU6050) và cảm biến chuyển động

(SW420, SW520). Camera kết nối với Raspberry Pi thông qua giao tiếp CSI để xử lý

hình ảnh và nhận diện trạng thái đội mũ. Các cảm biến lực và gia tốc giao tiếp qua

I2C, trong khi cảm biến từ trường và chuyển động sử dụng digital input. Các tín hiệu

từ khối này phản ánh tình trạng đội mũ đúng cách, phát hiện rung động bất thường

hoặc va chạm.
Khối xử lý dữ liệu sử dụng Raspberry Pi làm trung tâm xử lý. Dữ liệu cảm

biến được thu thập, phân tích và lưu trữ vào cơ sở dữ liệu nội bộ (database). Raspberry

Pi cũng đảm nhận việc phân tích ảnh bằng mô hình học sâu để xác định người dùng

có đội mũ bảo hiểm hay không. Khi đạt điều kiện an toàn, Raspberry Pi gửi lệnh điều

khiển thông qua HTTP nội bộ đến vi điều khiển ESP32, đóng vai trò là đơn vị thực

thi tín hiệu phần cứng. Kết nối giữa Raspberry Pi và ESP32 sử dụng mạng nội bộ

(local network) trong môi trường tích hợp.
Khối thực thi bao gồm buzzer cảnh báo và relay khởi động xe, được điều khiển

trực tiếp bởi ESP32. Khi hệ thống phát hiện hành vi vi phạm như không đội mũ hoặc

có va chạm, buzzer sẽ phát tín hiệu cảnh báo và relay sẽ ngắt, ngăn không cho xe

khởi động. Mô hình này có nét tương đồng với nghiên cứu của các cảm biến rung và

module GSM được tích hợp vào mũ bảo hiểm để phát hiện tai nạn và gửi cảnh báo tự

động đến số điện thoại đã định sẵn (S. Sekar và cộng sự, 2022) .

Khối truyền thông – hiển thị bao gồm module GPS, SIM GSM, LCD và giao

diện ứng dụng (app). Raspberry Pi và ESP32 sử dụng UART để giao tiếp với GPS và

module SIM nhằm gửi tin nhắn khẩn cấp và cung cấp vị trí người điều khiển trong

Trang 12

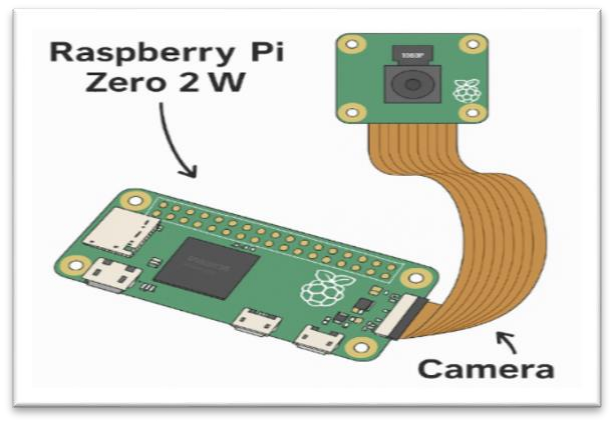
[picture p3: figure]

Thiết kế và phát triển mũ bảo hiểm IoT hỗ trợ giám sát an toàn giao thông và cảnh trường hợp xảy ra tai nạn. Màn hình LCD có thể hiển thị trạng thái hệ thống trực tiếp,

trong khi ứng dụng di động giúp người dùng giám sát tình trạng an toàn từ xa thông

qua giao diện người dùng.
Khối nguồn trong hệ thống mũ bảo hiểm IoT sử dụng pin 5V–3A để cung cấp

năng lượng cho toàn bộ thiết bị, bao gồm Raspberry Pi Zero 2W, ESP32, các cảm

biến và các module truyền thông như GPS và GSM. Nguồn pin phải đảm bảo dòng

điện đủ lớn để đáp ứng yêu cầu tiêu thụ đồng thời của nhiều linh kiện, đồng thời tích

hợp mạch bảo vệ quá dòng, quá áp và ngắn mạch nhằm tăng độ an toàn và tuổi thọ

hệ thống. Tùy theo nhu cầu sử dụng, hệ thống có thể mở rộng thêm cổng sạc USB

hoặc module sạc năng lượng mặt trời nhằm hỗ trợ hoạt động liên tục trong điều kiện

thực địa.

### 3.2 Thiết kế phần cứng

### 3.2.1 Khối cảm biến và nhận diện

Khối cảm biến và nhận diện là bộ phận đầu vào quan trọng, thu thập dữ liệu

về trạng thái đội mũ và hành vi người điều khiển. Các cảm biến được gắn trực tiếp

trên mũ hoặc thân xe, cho phép hệ thống giám sát liên tục và phản ứng theo thời gian

thực. Cách tiếp cận này tương tự mô hình tích hợp cảm biến rung và GPS trong nghiên

cứu về mũ bảo hiểm thông minh (Sobhana và cộng sự, 2021).

CHình 3-2 Camera với Raspberry Pi

Thành phần đầu tiên trong khối này là camera, sử dụng giao tiếp CSI (Camera

Serial Interface) để kết nối với Raspberry Pi như Hình 3-2. Camera có nhiệm vụ ghi

Trang 13

Thiết kế và phát triển mũ bảo hiểm IoT hỗ trợ giám sát an toàn giao thông và cảnh lại hình ảnh khuôn mặt người điều khiển, sau đó được xử lý bởi thuật toán học sâu

tích hợp trong hệ thống nhằm xác định người dùng có đội mũ bảo hiểm hay không.

Việc nhận diện hình ảnh được thiết kế để đảm bảo độ chính xác cao ngay cả trong

điều kiện người dùng đeo khẩu trang hoặc kính.

Hình 3-3 Cảm biến lực và bộ chuyển đổi ADC ADS1115
Thành phần tiếp theo trong khối là cảm biến lực như Hình 3-3 bên trái, được

bố trí tại 4 điểm tiếp xúc bên trong lòng mũ nhằm phát hiện áp lực từ đầu người dùng

khi đội mũ. Việc sử dụng 4 cảm biến giúp hệ thống đánh giá chính xác và đồng đều

lực phân bố ở các vị trí gồm trán, đỉnh đầu và 2 bên đầu, từ đó xác định mũ đã được

đội đúng cách hay chưa và xác định lực va chạm nếu có xảy ra. Các cảm biến lực này

cho tín hiệu đầu ra ở dạng analog, không thể đọc trực tiếp bằng Raspberry Pi do bo

mạch này không tích hợp sẵn bộ chuyển đổi ADC. Thông số kỹ thuật của cảm biến

lực được trình bày tại Bảng A.2 – Phụ lục A.
Để khắc phục, mô hình sử dụng module ADC ADS1115 như Hình 3-3 bên

phải, một bộ chuyển đổi tương tự và số với độ phân giải 16-bit, giao tiếp thông qua

I2C. Module này có thể đọc đồng thời nhiều kênh đầu vào, phù hợp với việc đọc dữ

liệu từ 4 cảm biến lực một cách chính xác và ổn định. Sau khi chuyển đổi sang tín

hiệu số, dữ liệu sẽ được gửi về Raspberry Pi để xử lý và xác định điều kiện đội mũ

hợp lệ. Thông số kỹ thuật của module ADC ADS1115 được nêu tại Bảng A.2 – Phụ

lục A.

Trang 14

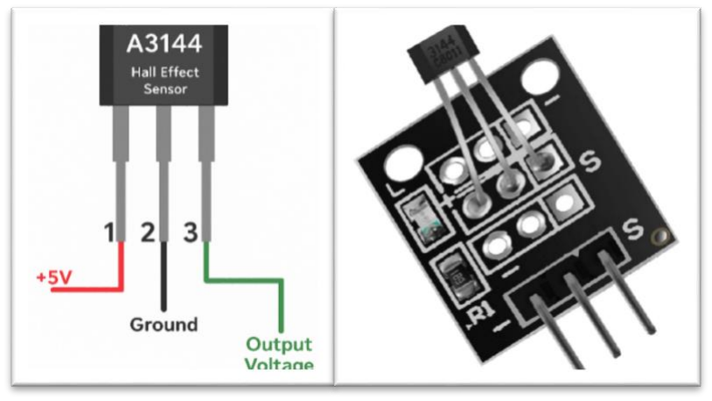
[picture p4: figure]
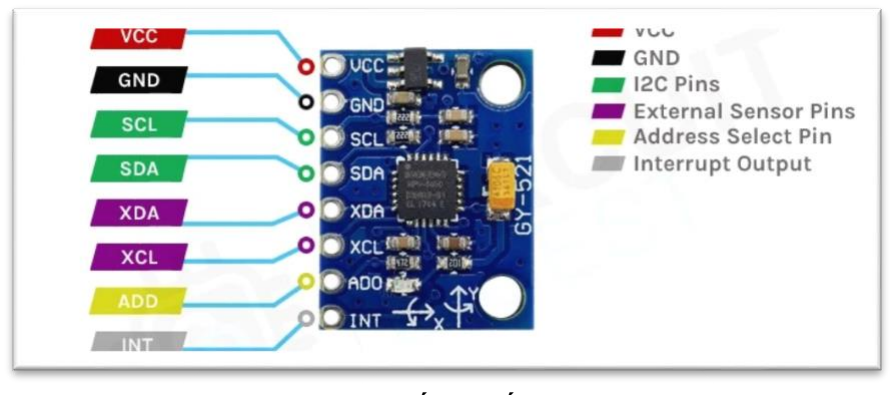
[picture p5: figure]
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

Cảm biến từ trường cũng được tích hợp tại vị trí quai mũ bảo hiểm nhằm phát

hiện trạng thái gài quai thông qua sự hiện diện hoặc không có mặt của từ trường từ nam châm gắn trên phần quai. Khi nam châm ở gần cảm biến từ trường được kết nối

với Raspberry Pi được minh họa trong Hình 3-4, hệ thống sẽ xác định rằng quai mũ

chưa được gài đúng cách và do đó không cho phép khởi động xe nhằm đảm bảo an

toàn. Ngược lại, khi cảm biến không phát hiện từ trường (tức là nam châm đã được

kéo ra khỏi vùng từ trường do quai đã được gài đúng vị trí), hệ thống sẽ xác nhận

người dùng đã gài quai hợp lệ và cho phép khởi động xe. Thông số của cảm biến Hall

trình bày ở Bảng A.2 – Phụ lục A.

Hình 3-4 Cảm biến Hall với Raspberry Pi

Hình 3-5 Cảm biến gia tốc MPU6050
Ngoài ra, hệ thống cũng được trang bị cảm biến gia tốc MPU6050 được thể

hiện trong Hình 3-5, có chức năng đo lường chuyển động ba chiều của mũ bảo hiểm

nhằm phát hiện các hiện tượng như tăng tốc đột ngột, rung động mạnh hoặc thay đổi

tư thế bất thường trong quá trình di chuyển. Dữ liệu thu được từ cảm biến gia tốc

được kết hợp với cảm biến chuyển động để xác định các tình huống tiềm ẩn nguy cơ

Trang 15

Thiết kế và phát triển mũ bảo hiểm IoT hỗ trợ giám sát an toàn giao thông và cảnh tai nạn, chẳng hạn như va chạm, trượt ngã, hoặc mất kiểm soát khi vận hành phương

tiện. Thông số kỹ thuật chi tiết của cảm biến MPU6050 được trình bày tại Bảng A.2-

Phụ lục A.
Bổ trợ cho việc phát hiện các trạng thái chuyển động bất thường, hệ thống còn

tích hợp hai cảm biến SW420 và SW520 nhằm nhận biết rung động kéo dài và dao

động mạnh từ phía phương tiện. Cảm biến SW420 phản ứng nhạy với rung dọc theo

trục thẳng đứng, trong khi SW520 phát hiện chuyển động lắc ngang. Khi cả hai cảm

biến này cùng kích hoạt liên tục trong một khoảng thời gian nhất định, hệ thống sẽ

xác định là có khả năng xảy ra va chạm hoặc mất kiểm soát, từ đó kích hoạt quy trình

cảnh báo và xử lý khẩn cấp. Bảng A.2 – Phụ lục A trình bày chi tiết thông số 2 cảm

biến này.

Tất cả các tín hiệu thu thập từ khối cảm biến và nhận diện sẽ được truyền về

Raspberry Pi để xử lý và phân tích. Dựa trên kết quả phân tích, hệ thống sẽ đưa ra

các quyết định điều khiển tương ứng, như cho phép khởi động xe, phát cảnh báo hoặc

gửi tín hiệu khẩn cấp. Việc tích hợp đồng bộ nhiều loại cảm biến trong cùng một hệ

thống giúp nâng cao khả năng nhận biết các tình huống thực tế, từ đó tăng cường mức

độ an toàn và tính chủ động cho người điều khiển phương tiện. Một số nghiên cứu

trước đó đã tích hợp các cảm biến như cảm biến rung và GPS vào mũ bảo hiểm thông

minh nhằm phát hiện va chạm, xác định vị trí và giám sát hành vi người lái (S.

Sobhana và cộng sự, 2021). Các tín hiệu sau xử lý được truyền đến thiết bị di động

hoặc trung tâm điều khiển để cảnh báo kịp thời.

### 3.2.2 Khối truyền thông và hiển thị

Khối truyền thông và hiển thị bao gồm các thành phần chính: module GPS,

module SIM GSM, màn hình LCD và giao diện ứng dụng di động (app). Đây là khối

chức năng đóng vai trò kết nối hệ thống với môi trường bên ngoài, đặc biệt trong các

tình huống khẩn cấp hoặc khi cần theo dõi trạng thái an toàn từ xa.

Raspberry Pi và ESP32 được cấu hình để giao tiếp với module GPS nằm bên

phải Hình 3-6 và module SIM nằm bên trái Hình 3-6, thông qua chuẩn UART

(Universal Asynchronous Receiver/Transmitter). Khi hệ thống phát hiện sự cố như

Trang 16

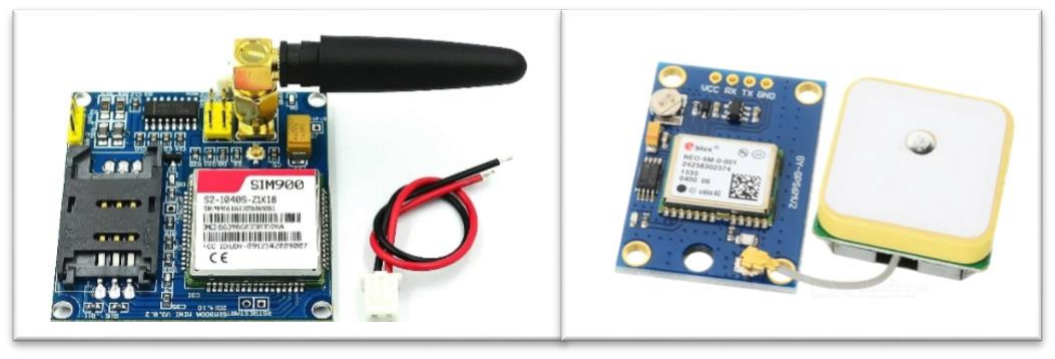
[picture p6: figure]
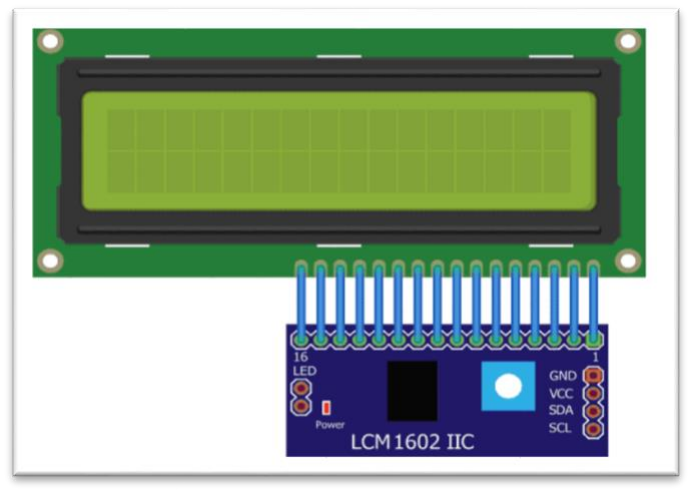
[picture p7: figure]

Thiết kế và phát triển mũ bảo hiểm IoT hỗ trợ giám sát an toàn giao thông và cảnh va chạm, mất cân bằng hoặc trạng thái nguy hiểm khác, Raspberry Pi sẽ thu thập dữ

liệu tọa độ từ module GPS, sau đó chuyển thông tin này sang module SIM để thực

hiện gửi tin nhắn khẩn cấp (SMS) đến số điện thoại đã được cấu hình trước, cơ chế

tương tự cũng được triển khai trong nghiên cứu với module GSM đảm nhiệm chức

năng liên lạc tự động khi có tai nạn của (Sekar và cộng sự, 2022). Trong trường hợp module SIM không có tín hiệu mạng hoặc gọi không thành công, hệ thống sẽ sử dụng

kết nối Wi-Fi để gửi email khẩn cấp đến người thân đã đăng ký trước, đảm bảo cảnh

báo được gửi đi kịp thời. Thông số kỹ thuật của module SIM900A và GPS NEO-6M

được trình bày tương ứng tại Bảng A.2 – Phụ lục A.

Hình 3-6 Module GSM SIM900A và GPS NEO6M

Hình 3-7 Màn hình LED LCD I2C
Màn hình LCD 16x02 giao tiếp I2C sử dụng hai chân SCL (đồng hồ) và chân

SDA (dữ liệu) để giao tiếp với ESP32. Màn hình LCD như Hình 3-7 này sẽ được tích

hợp để hiển thị các thông tin trạng thái hệ thống trong thời gian thực, như “An toàn”,

“Chưa đội mũ”, “Lỗi cảm biến” hoặc “Đang gửi cảnh báo”. Điều này giúp người điều

Trang 17

Thiết kế và phát triển mũ bảo hiểm IoT hỗ trợ giám sát an toàn giao thông và cảnh khiển có thể theo dõi trực tiếp tình trạng mũ bảo hiểm và hệ thống, góp phần nâng

cao mức độ tương tác và chủ động điều chỉnh hành vi nếu cần thiết.

Khối truyền thông và hiển thị đóng vai trò quan trọng trong việc kết nối giữa

hệ thống mũ bảo hiểm thông minh và người dùng, đảm bảo tính phản ứng nhanh,

giám sát liên tục và hỗ trợ kịp thời trong các tình huống khẩn cấp.

### 3.2.3 Khối thực thi

Khối thực thi trong hệ thống mũ bảo hiểm IoT chịu trách nhiệm thực hiện các

hành động phản hồi cuối cùng, chuyển đổi kết quả đánh giá từ khối xử lý trung tâm

thành các tín hiệu điều khiển cụ thể tác động lên phần cứng. Trong mô hình này, khối

thực thi bao gồm hai thành phần chính: buzzer cảnh báo được điều khiển trực tiếp bởi

Raspberry Pi và relay điều khiển mạch khởi động xe, được điều khiển bởi ESP32.

Hình 3-8 nằm bên trái là buzzer được sử dụng như một thiết bị cảnh báo âm

thanh, giúp thông báo trực tiếp đến người điều khiển khi phát hiện các tình huống vi

phạm như: không đội mũ, đội mũ sai cách, không gài quai hoặc xảy ra va chạm. Raspberry Pi là thiết bị chịu trách nhiệm xử lý tín hiệu cảm biến và phân tích hình

ảnh, do đó trung tâm này được cấu hình để xuất tín hiệu điều khiển trực tiếp đến

buzzer thông qua chân GPIO. Điều này giúp hệ thống có thể phát ra cảnh báo tức

thời, ngay khi phát hiện vi phạm, mà không cần thông qua ESP32, đảm bảo độ trễ

thấp và phản ứng nhanh.

Hình 3-8 Buzzer và module relay 5VDC
Trong khi đó, ESP32 đảm nhận nhiệm vụ điều khiển mạch khởi động của xe

thông qua module relay 1 kênh được minh họa phía bên phải trong Hình 3-8. Sau khi

Trang 18

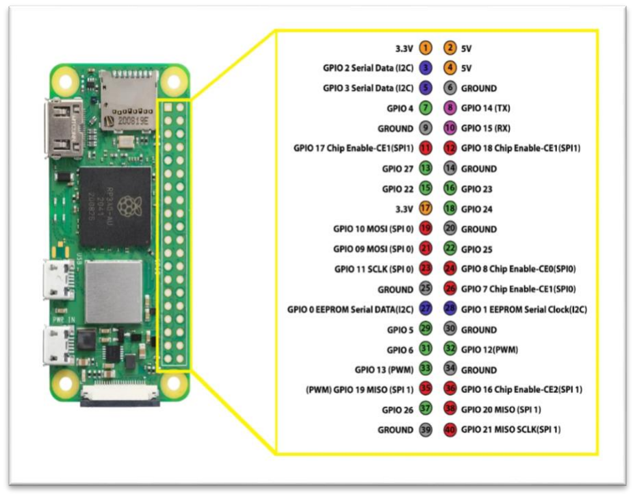
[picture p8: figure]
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

Raspberry Pi hoàn tất các kiểm tra về điều kiện an toàn và xác nhận người điều khiển

đủ điều kiện để vận hành xe, trung tâm hệ thống sẽ gửi một lệnh HTTP đến ESP32.

ESP32 sẽ xử lý lệnh này và kích hoạt relay trong một khoảng thời gian ngắn (khoảng

1–2 giây), cho phép dòng điện chạy qua mạch đề, từ đó khởi động xe. Trong trường

hợp không đạt điều kiện an toàn, relay sẽ không được kích hoạt và xe không thể khởi

động.

### 3.2.4 Khối xử lý dữ liệu điều khiển

Khối xử lý dữ liệu điều khiển đóng vai trò trung tâm trong hệ thống mũ bảo

hiểm thông minh, đảm nhận nhiệm vụ thu thập, phân tích dữ liệu từ cảm biến và hình

ảnh đầu vào, từ đó đưa ra các quyết định điều khiển tương ứng. Khối này bao gồm

hai thành phần chính: Raspberry Pi Zero 2W và vi điều khiển ESP32, được kết nối

với nhau thông qua giao thức HTTP nội bộ thông qua mạng Wi-Fi cục bộ.

Hình 3-9 Raspberry Pi Zero 2W
Trong mô hình mũ bảo hiểm IoT này, Raspberry Pi Zero 2W như được mình họa

trong Hình 3-9, đóng vai trò là “đầu não” trung tâm, xử lý toàn bộ thông tin thu thập

được từ các cảm biến lực, cảm biến từ trường, cảm biến chuyển động và dữ liệu hình

ảnh từ camera. Dựa trên thuật toán học sâu MobileNet SSD, Raspberry Pi nhận diện

Trang 19

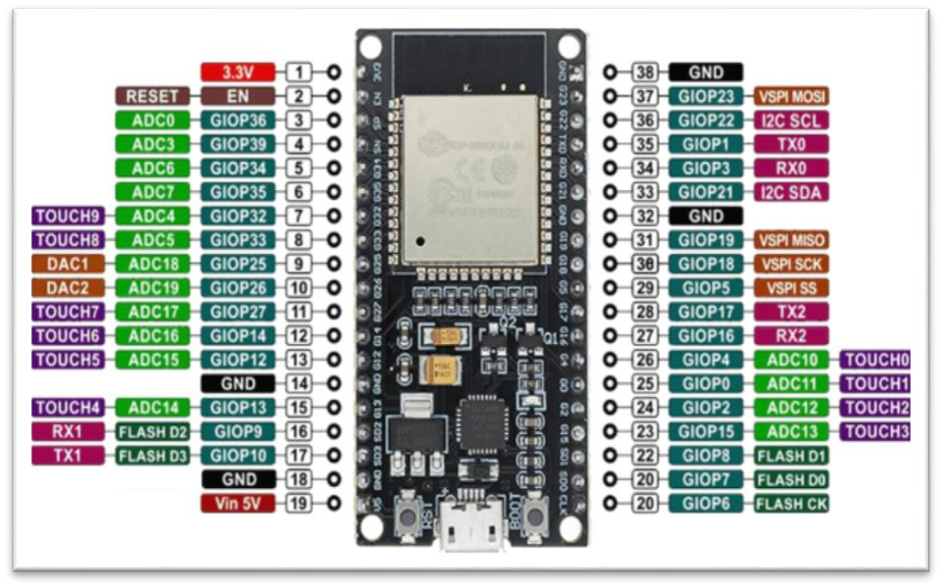
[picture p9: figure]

Thiết kế và phát triển mũ bảo hiểm IoT hỗ trợ giám sát an toàn giao thông và cảnh trạng thái đội mũ của người dùng (có đội, đội đúng cách hay không) đồng thời đánh

giá điều kiện gài quai và trạng thái chuyển động của người điều khiển. Sau khi phân

tích, nếu hệ thống xác nhận rằng tất cả điều kiện an toàn đã được thỏa mãn, Raspberry

Pi sẽ gửi một lệnh HTTP đến ESP32 để thực thi hành động tương ứng, ví dụ như cho

phép xe khởi động. Ngược lại, nếu có vi phạm, hệ thống sẽ phát ra cảnh báo và từ

chối khởi động xe nhằm đảm bảo an toàn.

Raspberry Pi là một máy tính nhúng nhỏ gọn, có khả năng chạy hệ điều hành

Linux và hỗ trợ đầy đủ các giao tiếp phần cứng như GPIO, I2C, UART, CSI và kết

nối mạng Wi-Fi. Với hiệu năng xử lý tương đối mạnh, bộ nhớ RAM linh hoạt và khả

năng lập trình đa dạng (Python, C/C++), Raspberry Pi cho phép thực hiện các tác vụ tính toán phức tạp như xử lý ảnh, phân tích dữ liệu cảm biến, lưu trữ cơ sở dữ liệu và

giao tiếp mạng. Thông số kỹ thuật của Raspberry Pi Zero 2W được dùng trong mô

hình được thể hiện chi tiết thông qua Bảng A.4 – Phụ lục A.

Hình 3-10 Vi điều khiển ESP32
Trong mô hình mũ bảo hiểm IoT, vi điều khiển ESP32 đảm nhận vai trò là

thiết bị chấp hành – thực hiện các hành động điều khiển cuối cùng dựa trên kết quả

phân tích và đánh giá từ bộ xử lý trung tâm Raspberry Pi Zero 2W. Sau khi Raspberry Pi hoàn tất việc xử lý ảnh (dựa trên mô hình học sâu MobileNet SSD) và phân tích

các tín hiệu từ hệ thống cảm biến (cảm biến lực, từ trường, gia tốc), chương trình sẽ

Trang 20

Thiết kế và phát triển mũ bảo hiểm IoT hỗ trợ giám sát an toàn giao thông và cảnh gửi một lệnh HTTP đến ESP32 nhằm kích hoạt hoặc từ chối việc khởi động xe tùy

theo điều kiện an toàn được xác nhận.

ESP32 là một module điều khiển mạnh mẽ và linh hoạt được sử dụng phổ biến

trong các ứng dụng IoT. Hình 3-10 điển hình cho mẫu ESP32 được phát triển bởi

Espressif Systems, là một series các vi điều khiển trên một vi mạch giá rẻ, năng lượng

thấp có hỗ trợ WiFi và dual-mode Bluetooth. Dòng ESP32 sử dụng bộ vi xử lý

Tensilica Xtensa LX6 ở cả hai biến thể lõi kép và lõi đơn,và bao gồm các công tắc

antenna tích hợp, RF balun, bộ khuếch đại công suất, bộ khuếch đại thu nhiễu thấp,

bộ lọc và module quản lý năng lượng. Thông số kỹ thuật của ESP32 được thể hiện

chi tiết trong Bảng A.3 – Phụ lục A.

Việc truyền nhận dữ liệu giữa Raspberry Pi Zero 2W và ESP32 được thực hiện

trong điều kiện mạng cục bộ. Trong môi trường này, Raspberry Pi đảm nhận vai trò

giao tiếp và xử lý dữ liệu từ các cảm biến nhận diện và điều khiển cảnh báo, trong

khi đó ESP32 đảm nhận vai trò thực thi theo lệnh điều khiển của Raspberry Pi.

Đầu tiên, Raspberry Pi sử dụng giao thức I2C để giao tiếp với bộ chuyển đổi

tín hiệu ADC ADS1115, qua đó thu thập dữ liệu từ bốn cảm biến lực được bố trí tại

các vị trí trọng yếu bên trong mũ bảo hiểm. Trong đó, hai cảm biến đặt tại đỉnh đầu

và trán đóng vai trò nhận diện người đội mũ, trong khi hai cảm biến còn lại đặt ở hai

bên đầu có nhiệm vụ phát hiện va chạm, đặc biệt trong trường hợp người đội mũ gặp

tai nạn có lực tác động mạnh từ phía trái hoặc phải. Sau khi xác nhận sự hiện diện của người đội mũ thông qua cảm biến lực, hệ thống tiếp tục sử dụng camera kết nối

với Raspberry Pi qua cổng CSI để thực hiện bước xác minh bổ sung về hình ảnh.

Cụ thể, dữ liệu hình ảnh từ camera sẽ được xử lý bởi mô hình học sâu

MobileNet SSD, hoạt động theo cơ chế nhận diện theo khối và phân loại đối tượng.

Mô hình này đã được tối ưu hóa để nhận diện khuôn mặt người ngay cả khi người

dùng đeo khẩu trang hoặc kính, từ đó đảm bảo độ chính xác cao trong các tình huống

thực tế. Nếu người dùng được xác minh đã đội mũ đúng cách, hệ thống sẽ chuyển

sang bước kiểm tra điều kiện gài quai nón. Tại đây, cảm biến từ trường Hall A3144

được gắn tại vành mũ, kết hợp với nam châm gắn trên dây quai, giúp phát hiện trạng

Trang 21

Thiết kế và phát triển mũ bảo hiểm IoT hỗ trợ giám sát an toàn giao thông và cảnh thái gài. Nếu cảm biến phát hiện tín hiệu từ trường ở khoảng cách gần (tức là nam

châm vẫn nằm trong vùng từ), hệ thống xác định rằng dây quai chưa được gài và sẽ

từ chối gửi lệnh kích hoạt relay cho ESP32. Ngược lại, khi cảm biến không ghi nhận

từ trường, hệ thống kết luận rằng quai nón đã được gài đúng cách, từ đó cho phép

ESP32 kích hoạt relay và cho phép xe máy khởi động.
Sau khi hoàn tất quá trình nhận diện và cho phép khởi động xe, hệ thống sẽ

tiếp tục thực hiện chức năng giám sát người dùng theo thời gian thực trong suốt quá

trình sử dụng mũ bảo hiểm và điều khiển phương tiện. Raspberry Pi sẽ giao tiếp với

cảm biến gia tốc MPU6050 thông qua giao thức I2C để theo dõi các hành vi như tăng

tốc đột ngột, xoay đầu, nghiêng đầu, hoặc té ngã. Đây là những dữ liệu quan trọng

nhằm phát hiện các tình huống nguy hiểm trong quá trình vận hành. Song song đó,

các cảm biến SW420 và SW520 được kết nối với ESP32 thông qua tín hiệu số (digital

input), có nhiệm vụ theo dõi chuyển động và phát hiện tai nạn ở cấp độ thiết bị ngoại

vi. Việc phân chia xử lý giữa Raspberry Pi và ESP32 giúp hệ thống vận hành ổn định

và có khả năng phản hồi nhanh chóng với nhiều loại tín hiệu cùng lúc.

Raspberry Pi và ESP32 kết nối với nhau qua giao thức HTTP trên mạng cục

bộ, đảm bảo trao đổi dữ liệu điều khiển và phân tích diễn ra nhanh chóng, ổn định.

Đồng thời, cả hai thiết bị giao tiếp với module định vị GPS NEO-6M và SIM900A

qua UART, cho phép xác định vị trí người dùng. Khi phát hiện va chạm hoặc hành vi bất thường, hệ thống sẽ lấy tọa độ từ GPS và sử dụng SIM để thực hiện cuộc gọi hoặc

gửi tin nhắn khẩn cấp đến số điện thoại đã được thiết lập trước, giúp phản ứng kịp

thời trong các tình huống nguy hiểm.

### 3.2.5 Khối nguồn

Khối nguồn đóng vai trò cung cấp năng lượng cho toàn bộ hệ thống mũ bảo

hiểm IoT, bao gồm các thành phần chính như Raspberry Pi Zero 2W, vi điều khiển

ESP32, các cảm biến, các module và các thiết bị ngoại vi khác. Nguồn năng lượng

chính của hệ thống được lựa chọn là power bank thương mại chuẩn 5V–3A, sử dụng

cell pin Li-ion tích hợp sẵn cùng mạch sạc và mạch bảo vệ bên trong. Loại nguồn này

đảm bảo cung cấp dòng điện ổn định và liên tục cho các thiết bị tiêu thụ điện năng

Trang 22

Thiết kế và phát triển mũ bảo hiểm IoT hỗ trợ giám sát an toàn giao thông và cảnh cao như Raspberry Pi Zero 2W và module SIM900A. Với thiết kế nhỏ gọn, dễ tháo

lắp và tiện lợi khi mang theo, power bank giúp tăng tính cơ động cho hệ thống mũ

bảo hiểm IoT.

Bảng 3-1 Công suất tiêu ước tính của hệ thống
Thành phần | Công suất ước tính
Raspberry Pi Zero 2W | 1.5 W
ESP32 | 0.3 ~ 0.4 W
SIM900A (khi gửi SMS/call) | ~1.0 W
GPS NEO-6M | ~0.06 W
MPU6050 + SW420 + SW520 | ~0.05 W
Buzzer + LCD | ~0.1 ~ 0.2 W
Tổng cộng (khi peak) | ≈ 2.5 ~ 3.0 W

Tính toán cho thấy, khi toàn bộ hệ thống hoạt động đồng thời ở trạng thái tải

cao nhất (bao gồm xử lý ảnh, gửi dữ liệu, phát cảnh báo và vận hành các cảm biến),

mức tiêu thụ điện năng ước tính vào khoảng 2.5 ~ 3W, trong đó Raspberry Pi Zero 2W tiêu thụ trung bình khoảng 1.5W, còn lại là cho ESP32, các cảm biến và các

module truyền thông. Bảng 3-1 mô tả chi tiết thông số công suất ước tính được dùng

trong hệ thống.

### 3.3 Thiết kế phần mềm

### 3.3.1 Lưu đồ giải thuật hệ thống

Lưu đồ giả thuật hệ thống của mô hình trong Hình 3-11 không chỉ mô tả logic

xử lý tuần tự của hệ thống mà còn thể hiện rõ cơ chế phản hồi theo vòng lặp, giúp hệ

thống hoạt động liên tục trong suốt quá trình sử dụng. Một điểm đáng chú ý là quá

trình xử lý được chia thành hai giai đoạn rõ rệt: giai đoạn xác minh điều kiện an toàn

trước khi khởi động xe (bao gồm kiểm tra đội mũ, nhận diện khuôn mặt và gài quai)

và giai đoạn giám sát thời gian thực sau khi phương tiện đã được khởi động.

Trang 23

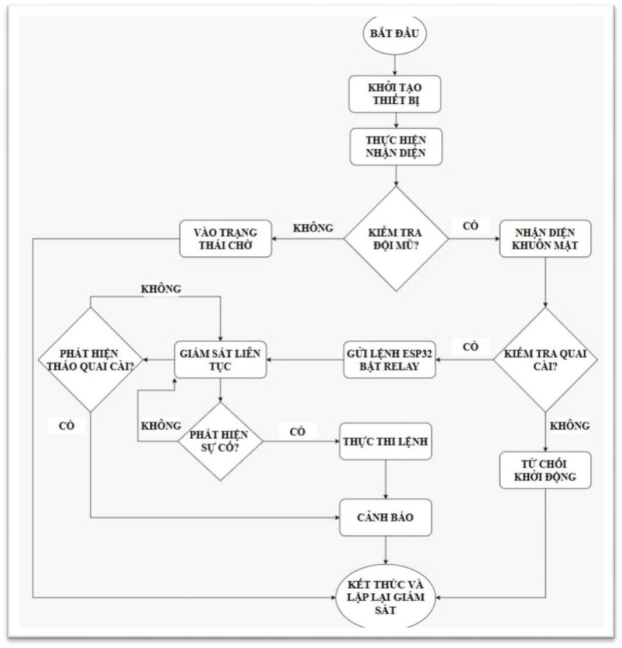
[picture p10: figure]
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

Ngoài ra, nhánh xử lý tình huống khẩn cấp được thiết kế song song với chức

năng ghi nhận trạng thái hệ thống, cho thấy khả năng vừa phản ứng nhanh với sự cố

vừa hỗ trợ lưu trữ dữ liệu phục vụ đánh giá và phân tích sau này. Cấu trúc giải thuật

theo hướng phân nhánh và tự động hóa như vậy là nền tảng vững chắc để hệ thống

có thể mở rộng thêm các chức năng nâng cao như học hành vi người dùng, cảnh báo

sớm nguy cơ tai nạn, hoặc tích hợp với nền tảng giám sát thông minh trong các phiên

bản tương lai.

Hình 3-11 Lưu đồ giải thuật hệ thống

### 3.3.2 Xây dựng chương trình nhận diện hình ảnh

Trong hệ thống mũ bảo hiểm IoT hỗ trợ giám sát an toàn giao thông, chức

năng nhận diện hình ảnh đóng vai trò then chốt nhằm đảm bảo người điều khiển

Trang 24

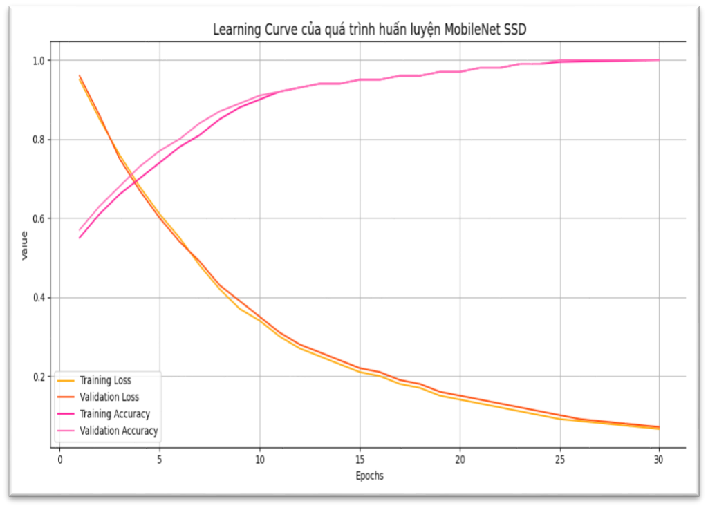
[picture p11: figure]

Thiết kế và phát triển mũ bảo hiểm IoT hỗ trợ giám sát an toàn giao thông và cảnh phương tiện thực sự đội mũ bảo hiểm đúng cách trước khi được phép khởi động xe.

Đặc biệt, hệ thống cần phải nhận diện chính xác trong các trường hợp người điều

khiển đeo khẩu trang hoặc kính mắt, đây những yếu tố có thể làm nhiễu quá trình

nhận diện khuôn mặt thông thường.
Để đáp ứng yêu cầu này, hệ thống lựa chọn mô hình MobileNet SSD làm thuật

toán chính cho quá trình nhận diện hình ảnh. Mô hình này kết hợp giữa mạng nerual

tích chập MobileNet, đây là một kiến trúc CNN nhẹ, được tối ưu hóa cho thiết bị có

tài nguyên hạn chế, cùng với thuật toán SSD có khả năng phát hiện đối tượng theo cơ

chế một bước, cho phép xử lý nhanh và phù hợp với bài toán thời gian thực. Cụ thể,

MobileNet sử dụng kỹ thuật convolution tách chiều sâu (depthwise separable

convolution), giúp giảm thiểu số lượng tham số và khối lượng tính toán, đồng thời

vẫn giữ được khả năng trích xuất đặc trưng hình ảnh hiệu quả. Việc kết hợp với SSD

giúp hệ thống phát hiện nhiều đối tượng cùng lúc, chỉ trong một lần suy luận, từ đó

đảm bảo hiệu năng cao ngay trên phần cứng hạn chế như Raspberry Pi Zero 2W.

Hình 3-12 Learning Curve của quá trình huấn luyện mô hình MobileNet SSD
Mục tiêu nhận diện ảnh trong hệ thống đặt ra là phát hiện các đối tượng thuộc

ba lớp chính: person (người), mask (khẩu trang) và glasses (kính mắt). Ngưỡng độ

Trang 25

Thiết kế và phát triển mũ bảo hiểm IoT hỗ trợ giám sát an toàn giao thông và cảnh chính xác yêu cầu là từ 50% trở lên, nhằm đảm bảo khả năng vận hành tin cậy trong

môi trường thực tế, nơi người dùng có thể thay đổi trạng thái đeo khẩu trang hoặc

kính. Khi phát hiện được ít nhất một trong ba đối tượng trên, hệ thống xác định người

điều khiển đã đảm bảo các yêu cầu an toàn cơ bản để khởi động phương tiện.

Hình 3-13 Kết quả nhận diện của mô hình
Quá trình huấn luyện mô hình MobileNet SSD được thực hiện trên nền tảng

Google Colab kết hợp cùng mã nguồn của TensorFlow, với tập dữ liệu được thu thập

được từ môi trường không gian mạng phổ biến (Nguyễn Chiến Thắng, 2022). Mô

hình được huấn luyện trong 30 epoch, sử dụng thuật toán tối ưu hóa Adam, với dữ

liệu được chia theo tỷ lệ 80% cho huấn luyện và 20% cho kiểm thử. Kết quả huấn

luyện được ghi nhận và theo dõi thông qua công cụ TensorBoard trên nền tảng Google

Colab, từ đó xuất đồ thị Learning Curve thể hiện sự hội tụ của mô hình trong quá

trình huấn luyện. Hình 3-12 biểu diễn đồ thị Learning Curve cho thấy giá trị hàm mất

mát (Loss) giảm dần đều theo số lượng epoch, trong khi độ chính xác (Accuracy)

tăng lên ổn định. Sau khoảng 25 epoch, độ chính xác trên tập kiểm thử đạt trên 95%,

đồng thời hàm mất mát duy trì ở mức thấp, cho thấy mô hình học hiệu quả và không

xảy ra hiện tượng quá khớp (overfitting). Quá trình xuất đồ thị Learning Curve được

thực hiện bằng cách lấy dữ liệu từ TensorBoard và trực quan hóa bằng thư viện

matplotlib, giúp đánh giá trực quan chất lượng mô hình sau khi huấn luyện. Kết quả

này chứng tỏ mô hình MobileNet SSD sau khi được tinh chỉnh hoàn toàn đáp ứng yêu cầu về tốc độ suy luận và độ chính xác cần thiết cho hệ thống nhận diện hình ảnh

trên mũ bảo hiểm IoT.

Trang 26

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

Kết quả nhận diện ảnh sau khi triển khai mô hình MobileNet SSD cho thấy

khả năng phát hiện khuôn mặt người điều khiển đạt độ chính xác tốt trong các điều

kiện khác nhau. Hình 3-13 thể hiện ví dụ kết quả nhận diện trên hai ảnh đầu vào có

góc chụp và điều kiện ánh sáng khác biệt. Trong các trường hợp này, mô hình có thể

nhận diện đúng vùng khuôn mặt với độ tin cậy lần lượt là 75.8% và 73.8%, đồng thời

vẽ chính xác bounding box bao quanh đối tượng. Các kết quả nhận diện này phù hợp

với ngưỡng yêu cầu (> 50%) đặt ra cho hệ thống, đảm bảo khả năng xác thực trạng

thái đội mũ khi áp dụng trong thực tế. Bên cạnh đó, việc mô hình duy trì được hiệu

năng ổn định trên nhiều mẫu ảnh khác nhau cũng cho thấy tính tổng quát tốt, giúp

tăng độ tin cậy khi triển khai trên thiết bị nhúng như Raspberry Pi Zero 2W.

### 3.3.3 Xây dựng chương trình giám sát hệ thống

Chương trình giám sát và cảnh báo là thành phần trung tâm của hệ thống mũ

bảo hiểm IoT, chịu trách nhiệm thu thập và phân tích dữ liệu từ các cảm biến lực,

cảm biến từ trường Hall, cảm biến gia tốc, cảm biến rung, cảm biến nghiêng và hình

ảnh từ camera. Dựa trên kết quả phân tích, chương trình sẽ đưa ra các quyết định điều

khiển nhằm đảm bảo an toàn cho người điều khiển phương tiện. Toàn bộ chương trình

được xây dựng và triển khai trên nền tảng Raspberry Pi Zero 2W, sử dụng ngôn ngữ

Python kết hợp với các thư viện chuyên dụng như tflite_runtime, sklearn, google-api-

python-client, RPi.GPIO và các thư viện xử lý ngoại vi khác.
Sơ đồ luồng xử lý của chương trình được thể hiện trong Hình 3-14, từ bước

đầu là khởi động, hệ thống lần lượt thực hiện nhận diện hình ảnh, kiểm tra quai gài

và cho phép khởi động xe khi đủ điều kiện an toàn. Sau khi khởi động, hệ thống

chuyển sang giám sát tổng thể, liên tục phân tích dữ liệu từ các cảm biến để phát hiện

nguy cơ tai nạn và thực hiện cảnh báo kịp thời. Ngoài ra, hệ thống luôn chờ lệnh thực

thi từ ứng dụng di động để đảm bảo khả năng phản hồi linh hoạt trong quá trình sử

dụng thực tế.

Quy trình hoạt động của chương trình được chia thành hai giai đoạn chính là kiểm tra điều kiện an toàn ban đầu và giám sát liên tục sau khi xe được khởi động. Ở

giai đoạn đầu, hệ thống sẽ kiểm tra lực từ cảm biến FSR để xác nhận người dùng đã

Trang 27

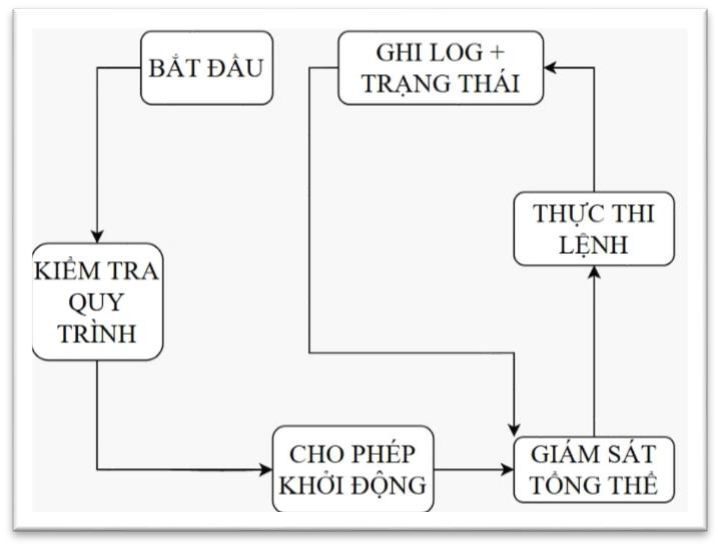
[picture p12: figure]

Thiết kế và phát triển mũ bảo hiểm IoT hỗ trợ giám sát an toàn giao thông và cảnh đội mũ đúng cách kết hợp nhận diện hình ảnh qua mô hình MobileNet SSD và kiểm

tra trạng thái gài quai bằng cảm biến Hall A3144. Khi đủ điều kiện, Raspberry Pi gửi

lệnh HTTP cho ESP32 kích hoạt relay khởi động xe, nếu không, hệ thống sẽ từ chối

khởi động xe. Khi xe đã khởi động, chương trình chuyển sang giám sát liên tục dữ

liệu từ MPU6050 được phân tích bằng mô hình Random Forest để nhận diện các hành

vi như té ngã, va chạm, tăng tốc đột ngột, cảm biến Hall kiểm tra quai gài, cảm biến

SW420 và SW520 giúp phát hiện rung động hoặc nghiêng xe để truyền tin về cho

Raspberry Pi xác thực lại tình trạng chung để đảm bảo độ chính xác. Nếu phát hiện

nguy hiểm, hệ thống sẽ ghi nhận để giao tiếp truyền tin và phát cảnh báo, đồng thời

ghi sự kiện kèm thông tin GPS lên Google Sheets. Ngoài ra, nếu trong quá trình cảnh

báo hệ thống không thể thực hiện cuộc gọi hay gửi tin qua module SIM do mất sóng,

chức năng gửi email tức thời kết hợp với hai phương thức gửi tin nhắn và gọi điện sẽ

đóng vai trò phụ trợ để đảm bảo được chức năng truyền thông tin cảnh báo của hệ

thống.

Hình 3-14 Sơ đồ luồng xử lý của hệ thống
Để nâng cao hiệu quả nhận diện các tình huống nguy hiểm trong quá trình

giám sát liên tục, hệ thống sử dụng thuật toán học máy Random Forest nhằm phân

tích dữ liệu dạng bảng thu thập từ cảm biến MPU6050 (Tiệp Vũ,2021). Cảm biến này

cung cấp các giá trị gia tốc (ax, ay, az) và vận tốc góc (gx, gy, gz) trên ba trục không

gian. Trước khi huấn luyện mô hình, vị trí gắn cảm biến của mũ bảo hiểm phải được

Trang 28

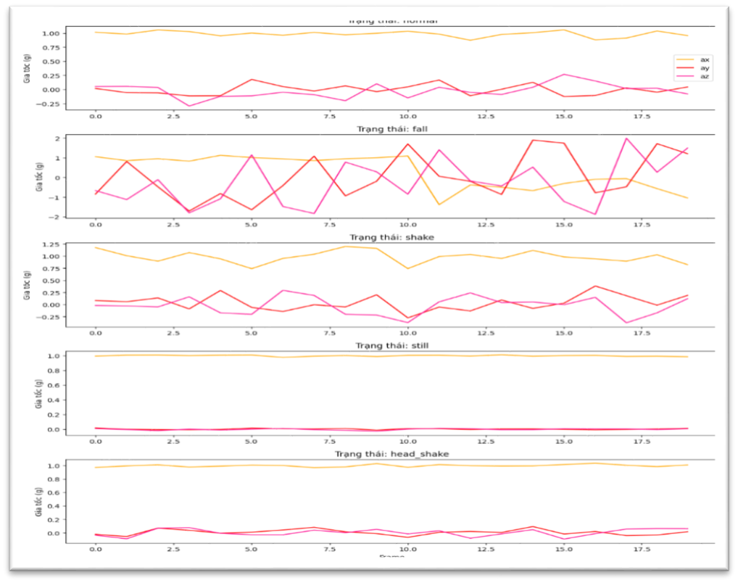
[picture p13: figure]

Thiết kế và phát triển mũ bảo hiểm IoT hỗ trợ giám sát an toàn giao thông và cảnh xác định nhằm biết được vị trí của trục x nằm ở đâu so với mặt đất (trạng thái đứng

yên ghi nhận ax ≈ +1g). Trong quá trình thu thập dữ liệu, vị trí gắn cảm biến

MPU6050 đã được cố định để đảm bảo tính nhất quán giữa dữ liệu huấn luyện và dữ

liệu vận hành thực tế. Cụ thể, cảm biến được gắn trên mũ sao cho khi ở trạng thái

đứng yên, các giá trị ghi nhận trung bình đạt được là ax ≈ +1.06g, ay ≈ 0.00g, az ≈ +0.15 ~ 0.20g. Việc chọn trục X hướng gần vuông góc với mặt đất giúp quá trình

phân tích và huấn luyện mô hình đạt độ chính xác cao hơn, đồng thời loại bỏ ảnh

hưởng của thay đổi tư thế hoặc vị trí lắp đặt cảm biến. Ngoài trục X làm trục tham

chiếu, các giá trị ay và az đóng vai trò nhận diện các dao động theo phương ngang

khi xảy ra rung động, nghiêng hoặc va chạm. Bên cạnh đó, các giá trị vận tốc góc gx,

gy, gz từ cảm biến gyroscope giúp hệ thống phát hiện các chuyển động quay hoặc lật

đột ngột của mũ, là dấu hiệu quan trọng để nhận diện tình huống té ngã hoặc va chạm.

Hình 3-15 Biểu đồ dao động của mũ bảo hiểm
Biểu đồ ở Hình 3-15 thể hiện dao động của ba trục gia tốc (ax, ay, az) thu được

từ cảm biến MPU6050 trong năm trạng thái hoạt động khác nhau của mũ bảo hiểm,

Trang 29

Thiết kế và phát triển mũ bảo hiểm IoT hỗ trợ giám sát an toàn giao thông và cảnh gồm: normal, fall, shake, still và head_shake. Dữ liệu được thu thập thực tế từ cảm

biến khi tiến hành mô phỏng các hành vi tương ứng, mỗi trạng thái lấy mẫu 100 khung

dữ liệu liên tiếp từ tập huấn luyện. Kết quả cho thấy, trong trạng thái normal, ax dao

động ổn định quanh ~1g, ay và az dao động nhỏ quanh 0, phản ánh trạng thái ổn định

của mũ. Khi xảy ra fall, các trục gia tốc dao động mạnh và không ổn định, đặc biệt là

ax và az là đặc trưng cho tình huống té ngã. Trạng thái shake cho thấy ay và az có

biên độ dao động lớn hơn normal nhưng không đến mức hỗn loạn như fall. Ở trạng

thái still, các trục dao động rất nhỏ, gần như ổn định tuyệt đối, trong khi trạng thái

head_shake thể hiện các dao động có tần suất cao trên ay và az do chuyển động quay

đầu. Qua biểu đồ có thể nhận thấy rằng việc kết hợp dữ liệu từ các trục ax, ay, az giúp

mô hình Random Forest phân biệt rõ ràng các hành vi khác nhau, từ đó nâng cao độ chính xác trong nhận diện tình huống thực tế.

### 3.3.4 Cấu trúc giao tiếp giữa các cảm biến và bộ xử lý

Hệ thống mũ bảo hiểm IoT tích hợp nhiều thành phần phần cứng và phần mềm,

liên kết chặt chẽ nhằm đảm bảo khả năng giám sát, cảnh báo và phản ứng kịp thời khi

có sự cố. Để các thành phần này phối hợp vận hành ổn định và đạt hiệu quả cao, quá

trình giao tiếp truyền dữ liệu giữa các thiết bị phải được thiết kế hợp lý, đồng bộ, đáp

ứng các yêu cầu về độ trễ thấp và độ tin cậy cao. Cấu trúc giao tiếp trong hệ thống

bao gồm: giao tiếp giữa Raspberry Pi Zero 2W và các cảm biến; giao tiếp giữa ESP32

và các cảm biến ngoại vi, module SIM900A; giao tiếp giữa Raspberry Pi và ESP32

thông qua HTTP REST API; và quy cách vận hành tổng thể của giao thức này trong

môi trường mạng cục bộ. Thiết kế phân tầng như vậy giúp hệ thống đạt được sự linh

hoạt, dễ mở rộng và có khả năng vận hành bền vững trong các điều kiện thực tế. Bảng

3-2 mô tả chi tiết các giao thức mà các thành phần giao tiếp với nhau trong hệ thống..

Bảng 3-2 Tóm tắt giao thức giao tiếp
Thiết bị | Cảm biến hoặc module | Giao thức giao tiếp
Raspberry Pi | MPU6050 | I2C
Raspberry Pi | ADS1115 + FSR + RFP | I2C

Trang 30

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

Raspberry Pi | Hall A3144, Buzzer | GPIO Digital
Raspberry Pi | Camera | CSI
Raspberry Pi | GPS NEO-6M | UART
Raspberry Pi ESP32 | Điều khiển chấp hành | HTTP REST API (Flask)
ESP32 | SW420, SW520, Relay | GPIO Digital
ESP32 | LCD-I2C | I2C
ESP32 | GSM SIM900A | UART (AT Command)

Trong hệ thống mũ bảo hiểm IoT, Raspberry Pi Zero 2W đóng vai trò trung

tâm xử lý dữ liệu cảm biến và giám sát tổng thể. Việc giao tiếp giữa Raspberry Pi và

các cảm biến được xây dựng dựa trên các giao thức tiêu chuẩn phù hợp với từng loại

tín hiệu: I2C cho các cảm biến tuyến tính và ADC ngoài, CSI cho camera truyền hình

ảnh độ phân giải cao, UART cho module GPS, và GPIO digital cho cảm biến trạng

thái. Cách sử dụng các giao thức này giúp đảm bảo tốc độ truyền dữ liệu ổn định,

giảm thiểu độ trễ, đồng thời tận dụng tối đa tài nguyên phần cứng sẵn có trên

Raspberry Pi. Đặc biệt, việc khai thác cổng CSI cho camera và giao tiếp I2C cho các

cảm biến cho phép Raspberry Pi thu nhận dữ liệu đồng bộ, phục vụ các thuật toán

nhận diện và phân tích hành vi một cách chính xác và hiệu quả trong thời gian thực. Vi điều khiển ESP32 trong hệ thống chủ yếu đảm nhiệm vai trò chấp hành và

giám sát ngoại vi. Các cảm biến ngoại vi như cảm biến rung SW420, cảm biến

nghiêng SW520, cùng module SIM900A được kết nối trực tiếp với ESP32 thông qua

các giao thức đơn giản nhưng hiệu quả như GPIO Digital và UART. Thiết kế này

giúp ESP32 có thể xử lý và phản ứng nhanh chóng đối với các sự kiện ngoại vi, giảm

tải cho Raspberry Pi và đảm bảo khả năng đáp ứng tốt trong các tình huống khẩn cấp.

Đặc biệt, việc giao tiếp UART giữa ESP32 và module GSM SIM900A cho phép

ESP32 có thể thực hiện trực tiếp các tác vụ gọi điện hoặc gửi SMS cảnh báo. Điều

này giúp hệ thống có khả năng hoạt động độc lập và duy trì liên lạc ngay cả khi

Raspberry Pi tạm thời không sẵn sàng hoặc mất kết nối mạng cục bộ.

Trang 31

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

### 3.3.5 Giao thức truyền thông giữa Raspberry Pi và ESP32

Giao tiếp giữa Raspberry Pi và ESP32 trong hệ thống đóng vai trò là kênh

truyền thông nội bộ quan trọng nhất, điều phối toàn bộ hoạt động của khối chấp hành.

Trong kiến trúc này, Raspberry Pi được cấu hình làm máy chủ HTTP server (Flask),

còn ESP32 đóng vai trò client, liên tục chờ nhận lệnh từ Raspberry Pi hoặc thực thi các request khi được yêu cầu. Phương thức giao tiếp được xây dựng dựa trên mô hình

client-server thông qua giao thức HTTP/1.1, đảm bảo sự đơn giản và khả năng mở rộng. Mỗi khi Raspberry Pi hoàn thành quá trình phân tích dữ liệu từ cảm biến và mô

hình học sâu, hệ thống sẽ tạo các HTTP request (theo phương thức GET hoặc POST),

gửi trực tiếp đến ESP32 thông qua mạng Wi-Fi nội bộ. Ví dụ, khi đủ điều kiện an

toàn, Raspberry Pi sẽ gửi request GET /api/relay?state=on đến ESP32, yêu cầu kích

hoạt relay khởi động xe. Các request khác có thể bao gồm lệnh bật/tắt buzzer hoặc

thay đổi trạng thái cảm biến phụ trợ.

Về phía ESP32, firmware được thiết kế để có một vòng lặp lắng nghe các

endpoint REST API được định nghĩa sẵn. Khi nhận được một HTTP request từ

Raspberry Pi, ESP32 sẽ phân tích các tham số trong URL hoặc phần body của request,

thực thi lệnh tương ứng trên phần cứng (bật/tắt GPIO cho relay hoặc buzzer), sau đó

trả về một HTTP response với mã trạng thái 200 “OK” hoặc thông báo lỗi nếu có sự

cố. Toàn bộ quá trình giao tiếp diễn ra trong thời gian thực, với độ trễ trung bình trong

mạng LAN cục bộ là dưới 50 ms, đảm bảo khả năng phản hồi kịp thời trong các tình

huống khẩn cấp.

HTTP (Hypertext Transfer Protocol) là một giao thức tầng ứng dụng hoạt động

theo mô hình client-server, trong đó client chủ động gửi các request và server phản hồi bằng các response tương ứng. Trong hệ thống mũ bảo hiểm IoT, HTTP đóng vai

trò như một lớp giao vận chính giữa Raspberry Pi và ESP32, cho phép truyền tải các

lệnh điều khiển và nhận phản hồi trạng thái một cách đơn giản và dễ kiểm thử. Các

phương thức HTTP được sử dụng trong hệ thống bao gồm GET (dùng để truy vấn

trạng thái hoặc gửi các lệnh có tính chất idempotent) và POST (dùng để gửi các lệnh

có nội dung hoặc tham số thay đổi).

Trang 32

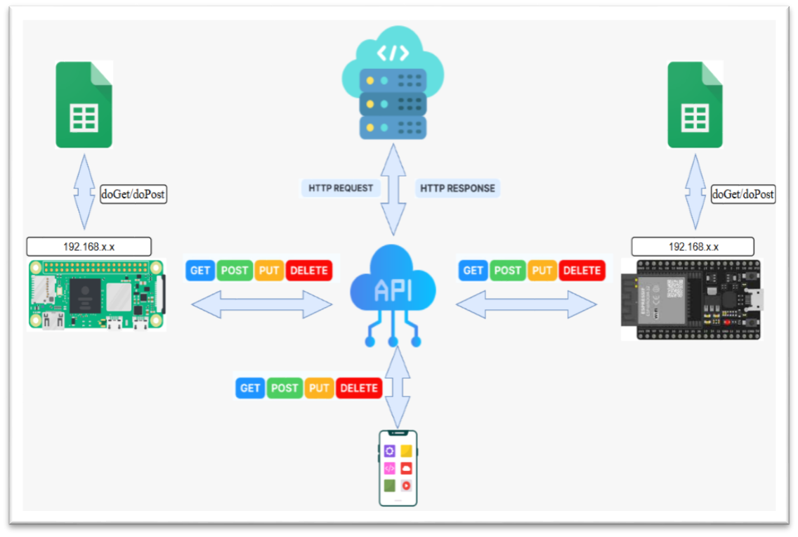
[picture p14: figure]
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

REST API (Representational State Transfer - Application Programming Interface) là một phong cách thiết kế API hiện đại, tuân thủ các nguyên lý REST,

giúp hệ thống đạt tính mở rộng và linh hoạt cao. Các nguyên tắc cơ bản của REST

bao gồm: phân tách rõ ràng giữa client và server (giúp các thành phần có thể phát

triển hoặc nâng cấp một cách độc lập), tính stateless (mỗi request HTTP là độc lập,

không lưu trạng thái phiên làm việc, giúp hệ thống dễ mở rộng và xử lý song song

hiệu quả), khả năng cacheable (có thể áp dụng kỹ thuật lưu cache để tăng tốc độ phản

hồi khi cần), tính uniform interface (tài nguyên được định danh qua URI và các hành

động được thực hiện bằng các phương thức HTTP tiêu chuẩn như GET, POST, PUT,

DELETE), và khả năng layered system (cho phép hệ thống có thể phân tầng hoặc mở

rộng thông qua các middleware hoặc proxy).

Hình 3-16 Kiến trúc giao tiếp của hệ thống
Hình 3-16 minh họa tổng quan kiến trúc giao tiếp HTTP REST API trong hệ

thống mũ bảo hiểm IoT, cho thấy sự tương tác giữa các thành phần: Raspberry Pi

Zero 2W, ESP32, dịch vụ Google Sheets và ứng dụng di động. Cả Raspberry Pi và ESP32 đều được gán địa chỉ IP trong mạng LAN nội bộ (192.168.x.x), cho phép hai

Trang 33

Thiết kế và phát triển mũ bảo hiểm IoT hỗ trợ giám sát an toàn giao thông và cảnh thiết bị này trao đổi trực tiếp thông qua các phương thức HTTP chuẩn như GET,

POST, PUT và DELETE. Raspberry Pi đóng vai trò là server Flask chính trong hệ thống, định nghĩa các REST endpoint để điều khiển các hành vi chấp hành (relay,

buzzer) hoặc ghi nhận trạng thái từ ESP32. Ngoài ra, thông qua các hàm doGet hoặc doPost, cả Raspberry Pi và ESP32 đều có khả năng tương tác với dịch vụ Google

Sheets để đồng bộ địa chỉ IP và hỗ trợ quá trình giao tiếp. Một thành phần quan trọng

trong sơ đồ là ứng dụng di động, được thiết kế để giao tiếp trực tiếp với tầng REST

API của Raspberry Pi và ESP32, cho phép người dùng điều khiển hoặc giám sát hệ

thống từ xa. Kiến trúc REST API hai chiều này giúp hệ thống đạt được tính mở rộng

cao, hỗ trợ giao tiếp đa nền tảng và đảm bảo khả năng vận hành linh hoạt trong môi

trường mạng cục bộ.

Việc sử dụng mô hình HTTP REST API giữa Raspberry Pi và ESP32 không chỉ giúp đơn giản hóa thiết kế hệ thống, mà còn tạo ra một giao diện truyền thông tiêu

chuẩn hóa, giúp dễ dàng kiểm tra, giám sát hoặc mở rộng các chức năng mới mà

không cần thay đổi phần cứng. Đặc biệt, các lệnh từ Raspberry Pi được xây dựng theo

mô hình idempotent (một lệnh gửi nhiều lần vẫn đảm bảo kết quả không thay đổi),

đảm bảo an toàn cho các tình huống mất gói hoặc kết nối mạng tạm thời.

### 3.4 Xây dựng giao diện người dùng

### 3.4.1 Định hướng thiết kế giao diện người dùng

Trong hệ thống mũ bảo hiểm thông minh IoT, ứng dụng di động đóng vai trò

là kênh giao tiếp chính giữa người dùng và hệ thống giám sát an toàn. Để đáp ứng tốt

yêu cầu về khả năng sử dụng, tính thân thiện và hiệu quả trong các tình huống thực

tế, việc thiết kế giao diện người dùng (UI) cần tuân thủ các định hướng rõ ràng, vừa

đảm bảo tính trực quan, dễ thao tác, vừa đảm bảo tính phản hồi nhanh và đồng bộ dữ

liệu theo thời gian thực.

Mục tiêu thiết kế giao diện của hệ thống tập trung vào việc cung cấp cho người

dùng một trải nghiệm nhất quán và dễ hiểu. Giao diện phải giúp người dùng nắm bắt

nhanh các thông tin trọng yếu như trạng thái an toàn của mũ bảo hiểm, cảnh báo nguy

Trang 34

Thiết kế và phát triển mũ bảo hiểm IoT hỗ trợ giám sát an toàn giao thông và cảnh hiểm, lịch sử sự kiện và vị trí hiện tại. Đồng thời, các thao tác điều khiển thiết bị, cấu

hình cảm biến hoặc quản lý thông tin cá nhân cũng cần được bố trí hợp lý, dễ tiếp cận

ngay cả khi người dùng không có nền tảng kỹ thuật chuyên sâu.

Về mặt thiết kế kỹ thuật, ứng dụng sử dụng kiến trúc client-server dựa trên

REST API để giao tiếp với Raspberry Pi và ESP32, cho phép ứng dụng đồng bộ dữ

liệu liên tục và kiểm soát được các trạng thái phần cứng từ xa. Tốc độ phản hồi và độ

ổn định được ưu tiên hàng đầu để đảm bảo rằng các lệnh điều khiển (như bật/tắt relay,

phát cảnh báo) cụ thể thực thi với độ trễ tối thiểu, dưới 50 ms trong mạng nội bộ.

Ngoài ra, do đối tượng người dùng có thể bao gồm nhiều nhóm tuổi và mức

độ am hiểu công nghệ khác nhau, giao diện được thiết kế theo hướng tối giản, các

biểu tượng trực quan kết hợp với thông báo rõ ràng giúp nâng cao khả năng sử dụng

trong mọi tình huống. Các biểu đồ trực quan như Pie Chart, Bar Chart và biểu đồ

đường thời gian cũng được tích hợp nhằm giúp người dùng dễ dàng theo dõi và đánh

giá các hành vi an toàn trong quá trình vận hành phương tiện.

Việc xây dựng giao diện trên nền tảng React Native giúp ứng dụng đạt được

tính đa nền tảng, dễ dàng triển khai trên cả hệ điều hành Android và iOS, đồng thời

tạo điều kiện thuận lợi cho việc nâng cấp, bảo trì hoặc mở rộng chức năng trong các

phiên bản tương lai.

### 3.4.2 Kiến trúc ứng dụng di động

Ứng dụng di động của hệ thống mũ bảo hiểm IoT được phát triển trên nền tảng

React Native có giao diện như Hình 3-17, cho phép xây dựng các ứng dụng đa nền

tảng cho cả Android và iOS chỉ từ một mã nguồn duy nhất. Với đặc thù là một hệ

thống giám sát an toàn giao thông thời gian thực, kiến trúc của ứng dụng được thiết

kế theo hướng phân tầng, giúp đảm bảo khả năng phản hồi nhanh, đồng bộ hóa dữ

liệu liên tục và duy trì sự ổn định khi vận hành trong môi trường mạng cục bộ.

Trong tầng giao diện người dùng, các màn hình chức năng được xây dựng

nhằm cung cấp trải nghiệm trực quan và thân thiện. Người dùng có thể dễ dàng theo

dõi trạng thái của mũ bảo hiểm, nhận thông báo về các tình huống nguy hiểm và thực

Trang 35

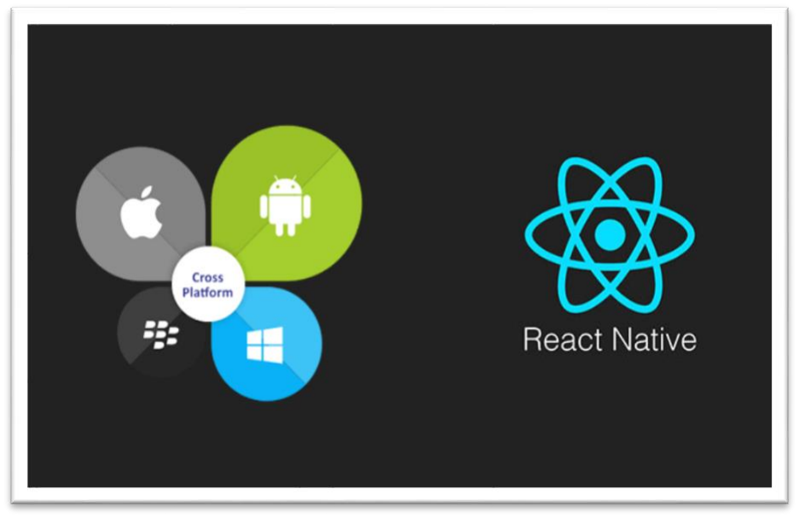
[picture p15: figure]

Thiết kế và phát triển mũ bảo hiểm IoT hỗ trợ giám sát an toàn giao thông và cảnh hiện các thao tác điều khiển thiết bị. Giao diện được tối ưu để hiển thị các thông tin

quan trọng một cách rõ ràng, đồng thời hỗ trợ các biểu đồ trực quan giúp người dùng

nhanh chóng nắm bắt tình trạng an toàn của thiết bị và hành vi lái xe.

Hình 3-17 Nền tảng React Native
Phía dưới lớp giao diện là tầng xử lý logic ứng dụng, nơi triển khai các cơ chế

kiểm soát cảm biến, điều khiển relay khởi động, phát cảnh báo âm thanh và đồng bộ

dữ liệu với hệ thống. Tất cả các hành động từ phía người dùng đều được xử lý tại tầng

này, sau đó được chuyển thành các yêu cầu HTTP REST API gửi tới Raspberry Pi.

Việc xây dựng tầng logic riêng biệt giúp ứng dụng duy trì sự linh hoạt, dễ bảo trì và

thuận tiện cho việc mở rộng các chức năng mới trong tương lai.

Tầng giao tiếp dữ liệu đóng vai trò cầu nối giữa ứng dụng và phần cứng của

hệ thống. Thông qua các API REST do Raspberry Pi cung cấp, ứng dụng có thể gửi

các lệnh điều khiển như bật/tắt cảm biến, kích hoạt relay hoặc buzzer, đồng thời truy

vấn trạng thái hiện tại của mũ bảo hiểm. Quá trình trao đổi dữ liệu giữa ứng dụng và

Raspberry Pi được thực hiện qua mạng Wi-Fi cục bộ với độ trễ trung bình dưới 50

ms, đảm bảo các phản hồi từ hệ thống được cập nhật nhanh chóng. Dữ liệu trao đổi

sử dụng định dạng JSON giúp tăng tính tương thích và dễ dàng mở rộng khi cần.

Song song với việc giao tiếp trực tiếp với Raspberry Pi, ứng dụng còn tích hợp

khả năng đồng bộ hóa dữ liệu với Google Sheets thông qua các API xây dựng trên

Trang 36

Thiết kế và phát triển mũ bảo hiểm IoT hỗ trợ giám sát an toàn giao thông và cảnh nền tảng Google Apps Script. Các thông tin quan trọng như trạng thái an toàn, lịch

sử cảnh báo và vị trí GPS của mũ bảo hiểm được cập nhật định kỳ lên Google Sheets,

giúp người dùng dễ dàng theo dõi, lưu trữ và phân tích thông tin lâu dài.

Ngoài ra, để đảm bảo tính ổn định của kết nối, ứng dụng được thiết kế với cơ

chế tự động cập nhật địa chỉ IP của Raspberry Pi từ Google Sheets. Bằng cách này,

ứng dụng luôn có thể xác định chính xác địa chỉ của Raspberry Pi ngay cả khi có sự

thay đổi mạng nội bộ. Cùng với đó, cơ chế polling liên tục với tần suất 3–5 giây cho

phép ứng dụng duy trì trạng thái đồng bộ với phần cứng, giúp người dùng luôn nhận

được các thông tin mới nhất từ hệ thống.

### 3.4.3 Các thành phần giao diện chính

Ứng dụng di động của hệ thống mũ bảo hiểm IoT được thiết kế gồm nhiều

thành phần giao diện chính, mỗi thành phần phục vụ một chức năng cụ thể nhằm giúp

người dùng dễ dàng theo dõi, kiểm soát và tương tác với hệ thống. Các thành phần

này được tổ chức dưới dạng các màn hình chức năng, cho phép chuyển đổi linh hoạt

thông qua menu điều hướng chính của ứng dụng.

Hình 3-18 Giao diện Dashboard và Menu
Giao diện Dashboard được minh họa ở Hình 3-18 bên trái đóng vai trò là trang tổng quan khi người dùng khởi động ứng dụng. Tại đây, các thông tin cơ bản như tên

người dùng, mã số sinh viên, ngày giờ hiện tại và trạng thái kết nối của hệ thống được

Trang 37

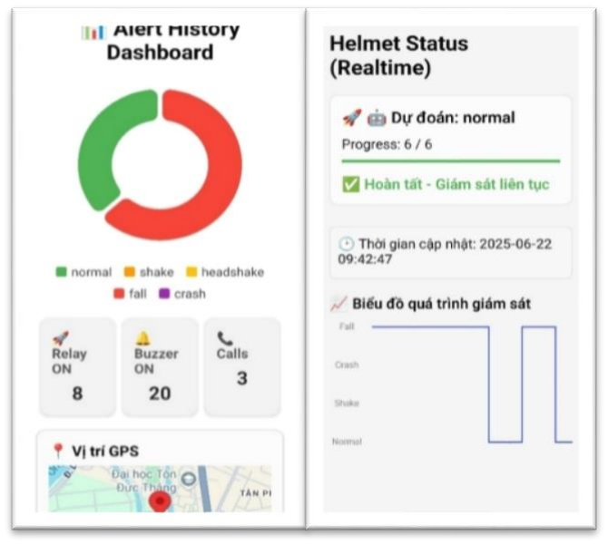
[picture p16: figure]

Thiết kế và phát triển mũ bảo hiểm IoT hỗ trợ giám sát an toàn giao thông và cảnh hiển thị một cách rõ ràng và trực quan. Từ Dashboard, người dùng có thể truy cập

nhanh vào Menu chính để điều hướng đến các chức năng chuyên sâu hơn.

Hình 3-19 Giao diện Alert History và Helmet Status
Giao diện Menu được thể hiện ở hình 3-18 bên phải cung cấp các lối tắt trực

tiếp đến các tính năng quan trọng của hệ thống, bao gồm: giám sát trạng thái mũ bảo

hiểm, xem lịch sử cảnh báo, theo dõi vị trí, cấu hình cảm biến, kiểm tra cảnh báo

video và quản lý thông tin cá nhân. Thiết kế của Menu hướng tới sự đơn giản, dễ

hiểu, giúp người dùng có thể thao tác thuận tiện ngay cả khi đang sử dụng ngoài thực

địa.

Giao diện Helmet Status được minh họa qua Hình 3-19 bên phải cho phép người dùng theo dõi trạng thái vận hành hiện tại của mũ bảo hiểm theo thời gian thực.

Các thông tin về tiến trình kiểm tra an toàn, kết quả nhận diện hình ảnh, trạng thái

cảm biến, cũng như biểu đồ diễn biến hành vi từ cảm biến MPU6050 được trình bày

một cách sinh động và dễ hiểu. Nhờ đó, người dùng có thể nhận biết ngay các tình

huống nguy hiểm hoặc bất thường.

Giao diện Alert History được mình họa ở hình 3-19 bên trái giúp người dùng

xem lại toàn bộ lịch sử các cảnh báo đã xảy ra. Dữ liệu được trực quan hóa dưới dạng biểu đồ tròn và biểu đồ cột, thể hiện tần suất các loại hành vi nguy hiểm như rung

động, va chạm hoặc té ngã. Ngoài ra, các thông tin liên quan đến số lần kích hoạt

Trang 38

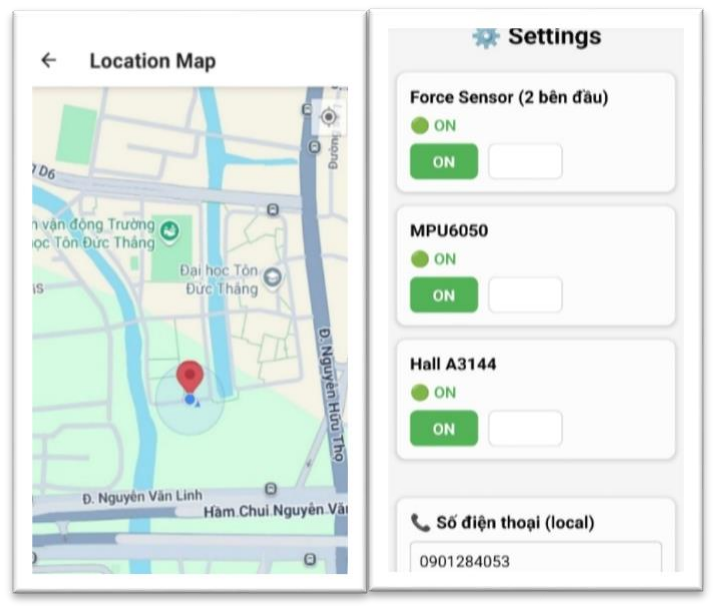
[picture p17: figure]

Thiết kế và phát triển mũ bảo hiểm IoT hỗ trợ giám sát an toàn giao thông và cảnh relay, buzzer hoặc cuộc gọi khẩn cấp cũng được thống kê rõ ràng, hỗ trợ người dùng

đánh giá mức độ an toàn trong quá trình vận hành.
Giao diện Location Map được mình họa qua Hình 3-20 bên trái cung cấp chức

năng theo dõi vị trí của mũ bảo hiểm hoặc người điều khiển phương tiện. Thông qua

GPS tích hợp, vị trí hiện tại của thiết bị được hiển thị trực tiếp trên bản đồ số, giúp

người dùng và người thân có thể biết được vị trí chính xác khi có sự cố xảy ra.

Hình 3-20 Giao diện Location Map và Settings
Giao diện Settings được thể hiện ở Hình 3-20 bên phải cho phép người dùng

chủ động cấu hình các thành phần cảm biến như Force Sensor, MPU6050 hoặc cảm

biến Hall, cũng như cập nhật và lưu số điện thoại liên hệ khẩn cấp. Ngoài ra, người

dùng có thể chủ động gửi yêu cầu kích hoạt cuộc gọi đến người thân thông qua chức

năng “Gọi chủ động” được tích hợp trong giao diện này.
Giao diện Game đang trong quá trình phát triển chưa hoàn thiện nhưng đây là

nơi để tích hợp các tính năng tương lai mà người dùng mong muốn hoặc có thể tạo

nên một trò chơi tương tác được với mũ bảo hiểm IoT bằng các chức năng thu thập

dữ liệu của cảm biến. Cuối cùng là giao diện User Info cho phép người dùng quản lý

thông tin cá nhân, bao gồm các thông tin cơ bản như họ tên, mã số sinh viên, lớp học,

chuyên ngành và số điện thoại.

Trang 39

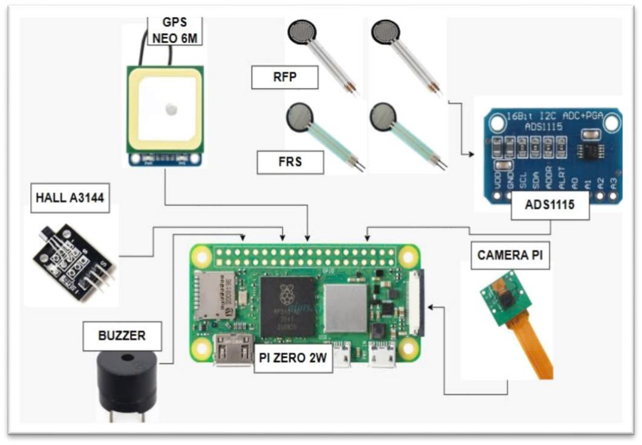
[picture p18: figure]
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

CHƯƠNG 4. KẾT QUẢ THI CÔNG VÀ THỰC NGHIỆM

### 4.1 Kết quả thiết kế hệ thống

Sau quá trình nghiên cứu, thiết kế và triển khai, hệ thống mũ bảo hiểm thông

minh IoT đã được hoàn thiện, bao gồm cả phần cứng và phần mềm. Toàn bộ hệ thống

được triển khai theo đúng các yêu cầu kỹ thuật đặt ra trong đề tài, đáp ứng đầy đủ về

chức năng, tính ổn định, khả năng giao tiếp giữa các thành phần và khả năng tích hợp

thực tế trên mũ bảo hiểm. Kết quả thiết kế thể hiện qua việc lắp ráp đầy đủ các linh

kiện phần cứng, lập trình và vận hành phần mềm trên các thiết bị, đồng thời tích hợp

thành công giao tiếp giữa các khối chức năng. Về phần cứng, hệ thống được chia

thành hai nhóm chính: hệ thống 1 sử dụng Raspberry Pi Zero 2W làm bộ xử lý trung

tâm và hệ thống 2 sử dụng ESP32 làm vi điều khiển chấp hành.

Hình 4-1 Linh kiện sử dụng ở hệ thống 1
Hệ thống 1 có nhiệm vụ thu thập dữ liệu từ các cảm biến MPU6050, ADS1115

(đọc tín hiệu từ 2 cảm biến RFP602 và 2 cảm biến FSR402), module GPS NEO6M,

Trang 40

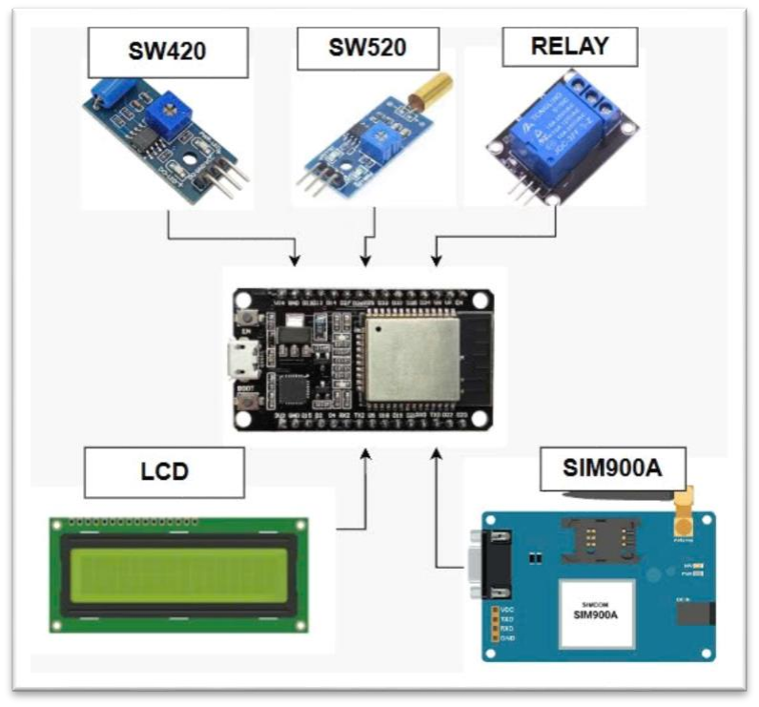
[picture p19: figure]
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

Camera Pi và phát cảnh báo qua Buzzer. Các kết nối phần cứng được thiết lập thông

qua các giao tiếp I2C, UART và GPIO, đảm bảo khả năng truyền nhận dữ liệu thời

gian thực. Hình 4-1 minh họa các linh kiện được sử dụng trong hệ thống 1.

Song song với đó, hệ thống 2 thực hiện xử lý tín hiệu từ cảm biến rung SW420,

cảm biến nghiêng SW520, điều khiển relay, phát cảnh báo âm thanh và gửi tin nhắn

SMS thông qua module SIM900A. Ngoài ra, ESP32 còn có khả năng hiển thị trạng

thái thông qua màn hình LCD và nhận lệnh điều khiển từ Raspberry Pi Zero 2W.

Hình 4-2 trình bày các linh kiện được sử dụng trong hệ thống 2 của mô hình.

Hình 4-2 Linh kiện sử dụng ở hệ thống 2
Về phần mềm, chương trình trên Raspberry Pi được phát triển bằng ngôn ngữ

Python, tích hợp các thư viện giao tiếp với cảm biến, xử lý hình ảnh và nhận diện

trạng thái đội mũ. Chương trình trên ESP32 được lập trình bằng nền tảng PlatformIO

trên phần mềm Visual Studio Code, đảm nhiệm các chức năng điều khiển thiết bị

ngoại vi và thực hiện các giao tiếp REST API với Raspberry Pi. Bên cạnh đó, ứng

dụng di động được xây dựng trên nền tảng React Native, đóng vai trò là giao diện

người dùng chính, cho phép giám sát trạng thái hệ thống theo thời gian thực, nhận

cảnh báo, điều khiển từ xa và đồng bộ dữ liệu với Google Sheets.

Trang 41

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

Ngoài các thành phần linh kiện điện tử, hệ thống còn được thiết kế bổ sung

hộp đựng chuyên dụng nhằm bảo vệ và cố định các module phần cứng khi tích hợp

vào mũ bảo hiểm. Hộp đựng được thiết kế bằng phần mềm SolidWorks, đảm bảo độ

chính xác cao về kích thước và tối ưu hóa không gian lắp đặt. Việc sử dụng thiết kế

3D giúp dễ dàng kiểm tra, hiệu chỉnh cấu trúc trước khi sản xuất thực tế. Sau khi thiết

kế hoàn chỉnh, hộp đựng được gia công bằng công nghệ in 3D với chất liệu nhựa chịu

va đập, phù hợp với các điều kiện sử dụng thực tế trên phương tiện giao thông. Thiết

kế hộp không chỉ giúp bảo vệ các linh kiện khỏi các tác động cơ học bên ngoài mà

còn đảm bảo khả năng thoát nhiệt và bố trí dây dẫn một cách gọn gàng, thuận tiện

cho quá trình bảo trì và nâng cấp sau này. Hình 4-3 thể hiện mô hình thiết kế 3D của

hộp đựng linh kiện trong hệ thống.

Hình 4-3 Mô hình 3D của hộp đựng linh kiện
Hệ thống sau khi lắp ráp hoàn chỉnh đã được tích hợp trực tiếp lên mũ bảo

hiểm thực tế thông qua hộp đựng thiết kế bằng phần mềm SolidWorks và gia công

bằng công nghệ in 3D. Thiết kế hộp đựng được tối ưu để ôm sát phần sau của mũ,

đảm bảo sự gọn nhẹ, giảm lực cản không khí khi di chuyển và đồng thời bảo vệ an

toàn cho các module điện tử bên trong. Các dây dẫn tín hiệu và dây nguồn được bố

trí hợp lý, sử dụng ống gen co và dây rút để cố định chắc chắn dọc theo thành mũ,

giúp giảm thiểu hiện tượng rung lắc hoặc đứt gãy trong quá trình sử dụng. Vị trí lắp

đặt được tính toán nhằm đảm bảo không gây cản trở cho người dùng khi đội mũ, đồng

Trang 42

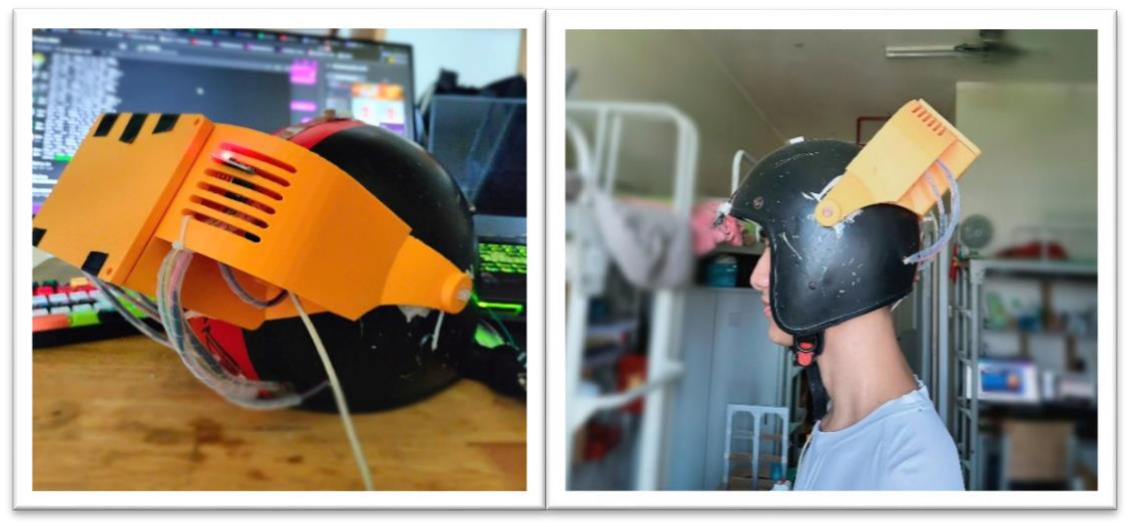
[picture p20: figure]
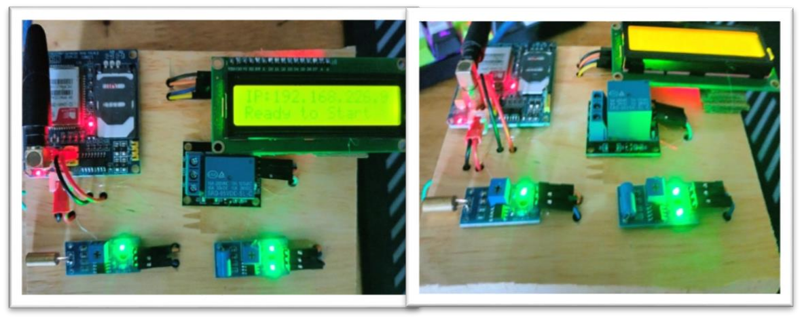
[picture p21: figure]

Thiết kế và phát triển mũ bảo hiểm IoT hỗ trợ giám sát an toàn giao thông và cảnh thời không làm tăng đáng kể trọng lượng mũ, giữ được sự thoải mái khi vận hành.

Qua quá trình lắp ráp thực tế và kiểm tra thử nghiệm, hệ thống cho thấy khả năng vận

hành ổn định, các thành phần được cố định chắc chắn, đảm bảo khả năng chống rung

và chịu va đập khi di chuyển trên đường. Hình 4-4 trình bày hình ảnh lắp ráp thực tế

của hệ thống mũ bảo hiểm thông minh IoT.

Hình 4-4 Mô hình nón bảo hiểm hoàn thiện

Hình 4-5 Mô hình giả lập hệ thống trên phương tiện
Mô hình phần cứng được thiết kế và lắp ráp trên một bề mặt phẳng nhằm mô

phỏng vị trí gắn thực tế trên thân phương tiện. Cấu trúc gồm các thành phần chính

như module SIM900A, vi điều khiển ESP32, relay điều khiển nguồn, màn hình hiển

thị LCD I2C và các cảm biến SW420, SW520. Mạch được bố trí gọn gàng, đảm bảo

khả năng quan sát và kết nối dễ dàng khi lắp đặt hoặc kiểm tra. Trong mô hình thực

tế ở Hình 4-5, module SIM900A (bên trái) thực hiện chức năng liên lạc khẩn cấp

Trang 43

Thiết kế và phát triển mũ bảo hiểm IoT hỗ trợ giám sát an toàn giao thông và cảnh thông qua cuộc gọi. Màn hình LCD I2C (bên phải) hiển thị địa chỉ IP và trạng thái hệ

thống. Phía dưới là relay khởi động và hai cảm biến rung: SW420 phát hiện rung

động theo phương thẳng đứng, SW520 phản ứng với dao động nghiêng. Hai cảm biến

này hoạt động song song để phát hiện các tình huống như va chạm, rung lắc mạnh

hoặc trượt ngã kéo dài. Nếu cả hai cảm biến kích hoạt liên tục trong thời gian định

ngưỡng (≥ 3 giây), hệ thống sẽ xử lý sự kiện và đưa ra quyết định cảnh báo gọi điện

và gửi email.
Kết luận, qua quá trình thiết kế, lắp ráp và thử nghiệm ban đầu, hệ thống mũ

bảo hiểm thông minh IoT đã được hoàn thiện đầy đủ cả về phần cứng lẫn phần mềm.

Các linh kiện được bố trí hợp lý, đảm bảo an toàn khi tích hợp lên mũ bảo hiểm thực

tế. Phần mềm vận hành ổn định, giao tiếp giữa các thành phần diễn ra chính xác và

có độ trễ thấp. Toàn bộ hệ thống đã sẵn sàng bước vào giai đoạn kiểm thử thực tế

nhằm đánh giá hiệu quả hoạt động và khả năng áp dụng trong các tình huống phù hợp

với mục tiêu thực nghiệm mô hình học thuật.

### 4.2 Kiểm thử hệ thống và vận hành thực tế

Sau khi hoàn thiện phần cứng và phần mềm, hệ thống mũ bảo hiểm thông minh

IoT đã được tiến hành kiểm thử thực tế nhằm đánh giá khả năng vận hành, độ ổn định

và mức độ đáp ứng các yêu cầu kỹ thuật đề ra. Quá trình kiểm thử được thực hiện

trên mũ bảo hiểm thực tế đã lắp đặt đầy đủ các linh kiện, tích hợp với hộp đựng 3D

và kết nối với ứng dụng di động. Các thử nghiệm được tiến hành trong các điều kiện

vận hành thực tế trên đường phố với nhiều tình huống khác nhau để kiểm tra khả năng

đáp ứng của hệ thống.

Quá trình kiểm thử được chia thành hai giai đoạn chính. Ở giai đoạn đầu, kiểm

thử khả năng khởi động hệ thống: khi người dùng đội mũ, hệ thống lần lượt kiểm tra

các điều kiện an toàn bao gồm: lực cảm biến FSR đạt ngưỡng yêu cầu, nhận diện hình

ảnh người đội mũ có độ chính xác trên 50% qua mô hình MobileNet SSD, và trạng thái gài quai mũ đúng cách thông qua cảm biến Hall. Khi hội đủ các điều kiện,

Raspberry Pi sẽ gửi lệnh HTTP cho ESP32 để kích hoạt relay cho phép xe khởi động.

Trang 44

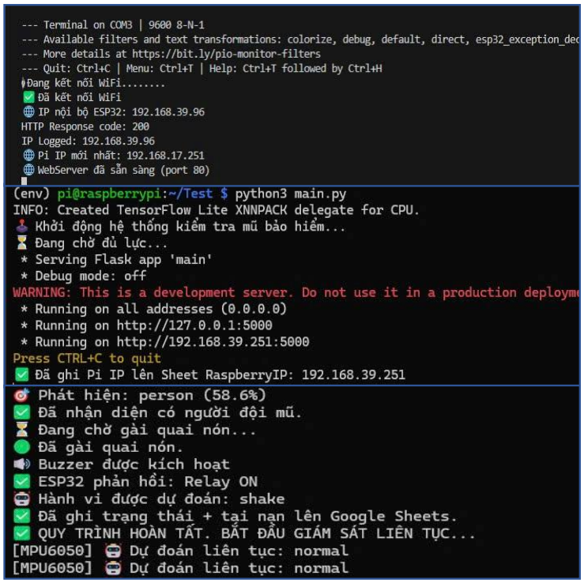
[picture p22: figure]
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

Qua quá trình thử nghiệm, hệ thống vận hành ổn định với độ trễ trung bình từ khi đội

mũ đến khi cho phép khởi động xe là khoảng 5–7 giây, đảm bảo tính tiện lợi và an

toàn cho người sử dụng.

Trong giai đoạn tiếp theo, hệ thống chuyển sang trạng thái giám sát liên tục

trong quá trình vận hành xe. Các cảm biến MPU6050, SW420 và SW520 hoạt động

đồng bộ, ghi nhận liên tục các hành vi của người điều khiển. Khi phát hiện các hành

vi nguy hiểm hoặc tình huống va chạm, hệ thống phát cảnh báo tức thời qua buzzer

và gửi thông báo về ứng dụng di động. Đặc biệt, khi mô phỏng các tình huống va

chạm nghiêm trọng, hệ thống đã tự động thực hiện cuộc gọi khẩn cấp thông qua

module SIM900A với thời gian phản hồi trung bình dưới 10 giây kể từ khi phát hiện

sự kiện.

Hình 4-6 Giai đoạn chạy thử hệ thống
Quá trình kiểm thử thực tế được ghi nhận qua các nhật ký hoạt động của hệ

thống. Hình 4-6 minh họa sơ bộ quá trình khởi động và vận hành thực tế của hệ thống

mũ bảo hiểm thông minh IoT. Trong đó thể hiện các bước: Raspberry Pi khởi động

Trang 45

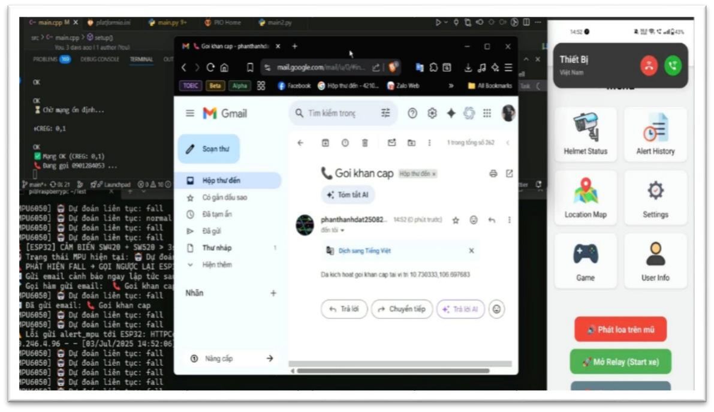
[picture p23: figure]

Thiết kế và phát triển mũ bảo hiểm IoT hỗ trợ giám sát an toàn giao thông và cảnh dịch vụ Flask, kiểm tra cảm biến lực và nhận diện người đội mũ bằng mô hình học

sâu MobileNet SSD, kiểm tra trạng thái gài quai mũ, ghi nhận IP thiết bị lên Google

Sheets, điều khiển relay khởi động xe thông qua ESP32. Bên cạnh đó, ESP32 vận

hành WebServer, kết nối Wi-Fi, phản hồi các lệnh điều khiển từ Raspberry Pi. Sau

khi hoàn tất các bước kiểm tra an toàn, hệ thống chuyển sang chế độ giám sát liên

tục, sử dụng cảm biến MPU6050 và các cảm biến phụ trợ để nhận diện hành vi vận

hành, đồng thời ghi nhận và phản hồi kịp thời các tình huống nguy hiểm. Nhật ký

hoạt động cho thấy các thành phần phần cứng và phần mềm phối hợp ổn định, đáp

ứng đúng yêu cầu kỹ thuật đề ra.

Hình 4-7 Kiểm thử chức năng giám sát
Để kiểm chứng khả năng phản ứng trong tình huống thực tế, hệ thống đã được

thử nghiệm với kịch bản mô phỏng tai nạn nhằm đánh giá tính chính xác và độ tin

cậy của cơ chế cảnh báo khẩn cấp. Hình 4‑7 ghi lại quá trình vận hành của hệ thống

trong một tình huống mô phỏng tai nạn thực tế. Tại thời điểm này, cảm biến

MPU6050 liên tục ghi nhận trạng thái "fall", đồng thời hai cảm biến rung SW420 và

SW520 cùng phát hiện rung động kéo dài trên 3 giây. ESP32 ngay lập tức gửi tín hiệu cảnh báo về Raspberry Pi thông qua API. Sau khi xác nhận điều kiện tai nạn thực sự

xảy ra, hệ thống tiến hành đồng thời hai tác vụ khẩn cấp, một là gửi thư điện tử cảnh

Trang 46

Thiết kế và phát triển mũ bảo hiểm IoT hỗ trợ giám sát an toàn giao thông và cảnh báo đến địa chỉ được cấu hình sẵn, trong đó đính kèm tọa độ GPS tại thời điểm sự cố

(10.730333, 106.697683) và hai là kích hoạt cuộc gọi tự động đến số điện thoại người

thân thông qua module SIM900A. Trong tình huống thực nghiệm được minh họa tại

Hình 4-8, hệ thống ghi nhận một kịch bản giám sát trong đó xuất hiện lực tác động

lên hai cảm biến được bố trí ở hai bên vành phía trong của mũ, khu vực không tiếp

xúc trực tiếp với đầu người đội. Ngay lập tức, hệ thống xác định đây là dấu hiệu bất

thường trong quá trình giám sát và nhanh chóng phát tín hiệu điều khiển buzzer phát

ra âm thanh cảnh báo tại chỗ. Đồng thời, hệ thống thực hiện quy trình ghi nhận sự

kiện và gửi tin nhắn SMS đến số điện thoại đã được thiết lập trước. Để tăng độ tin

cậy, một email dự phòng với nội dung cảnh báo tương tự cũng được gửi đến địa chỉ

định sẵn, nhằm đảm bảo thông tin vẫn được chuyển đi trong trường hợp gặp sự cố

như mất tín hiệu hoặc lỗi gửi tin nhắn.

Hình 4-8 Kiểm thử chức năng giám sát bất thường
Qua quá trình kiểm thử thực tế, hệ thống đã thể hiện khả năng phản ứng nhanh

chóng và chính xác trước các tình huống mô phỏng tai nạn. Các bước xử lý được hiển

thị rõ ràng trong nhật ký dòng lệnh, cho thấy quy trình vận hành tuân thủ đúng theo

thiết kế ban đầu. Song song đó, giao diện ứng dụng di động vẫn duy trì hoạt động ổn

Trang 47

Thiết kế và phát triển mũ bảo hiểm IoT hỗ trợ giám sát an toàn giao thông và cảnh định, hỗ trợ người dùng theo dõi trạng thái hệ thống theo thời gian thực và điều khiển

từ xa thông qua các chức năng như phát loa cảnh báo, khởi động hoặc tắt động cơ xe,

cũng như giám sát vị trí GPS của người điều khiển. Kết quả kiểm thử xác nhận sự

phối hợp nhịp nhàng và hiệu quả giữa các thành phần phần cứng, phần mềm và giao

diện người dùng. Điều này không chỉ đảm bảo độ tin cậy mà còn nâng cao tính kịp

thời của hệ thống trong việc xử lý và phản hồi các tình huống khẩn cấp, góp phần

tăng cường an toàn cho người tham gia giao thông.

### 4.3 Đánh giá hiệu suất hệ thống

Hiệu suất của hệ thống được đánh giá thông qua các chỉ số về tốc độ xử lý, độ

chính xác nhận diện, độ trễ phản hồi và thời lượng hoạt động, được trình bày trong

Bảng 4-1. Qua kết quả đo đạc, hệ thống cho thấy khả năng xử lý ổn định, đáp ứng

yêu cầu kỹ thuật đề ra. Mô hình nhận diện hình ảnh hoạt động tốt ngay trên nền tảng

phần cứng hạn chế, với tốc độ xử lý phù hợp cho ứng dụng thời gian thực. Giao tiếp

giữa Raspberry Pi và ESP32 có độ trễ rất thấp, đảm bảo khả năng phản hồi nhanh với

các tình huống bất thường

Bảng 4-1 Hiệu suất quan sát được của hệ thống
Thông số đánh giá | Giá trị quan sát/đo được
Thời gian khởi động Raspberry Pi và Flask server | ~10–15 giây
Thời gian kiểm tra an toàn (FSR + Hall + nhận diện ảnh) | ~5–10 giây
Tốc độ xử lý MobileNet SSD trên Pi Zero 2W | ~2.5–3 FPS
Độ chính xác nhận diện ảnh (ánh sáng tốt) | ≥ 60%
Độ chính xác nhận diện ảnh (ánh sáng yếu) | 40-60%

Trang 48

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

Ngưỡng nhận diện đạt yêu cầu | ≥ 50%
Độ trễ giao tiếp HTTP giữa Pi ↔ ESP32 (LAN) | < 50 ms
Thời gian phản hồi buzzer khi phát hiện fall/crash | < 1 giây
Thời gian từ phát hiện sự kiện đến thực hiện cuộc gọi/gửi sms/gửi email | < 10 giây
Thời gian hoạt động liên tục (battery 5000 mAh) | ~2.5–3 giờ

Qua các chỉ số trên, có thể nhận thấy hiệu suất của hệ thống đáp ứng tốt các

yêu cầu kỹ thuật đề ra. Quá trình kiểm tra điều kiện an toàn trước khi khởi động xe

diễn ra nhanh, thuận tiện cho người dùng. Mô hình nhận diện ảnh MobileNet SSD

cho kết quả chính xác và ổn định trên nền tảng phần cứng hạn chế như Raspberry Pi

Zero 2W. Độ trễ trong giao tiếp giữa Raspberry Pi và ESP32 ở mức rất thấp, đảm bảo

khả năng phản hồi kịp thời khi xảy ra các tình huống nguy hiểm. Các hành động cảnh

báo và gọi điện khẩn cấp đều được thực hiện với tốc độ phù hợp, có khả năng hỗ trợ

hiệu quả trong các tình huống thực tế. Thời lượng hoạt động khi sử dụng nguồn pin

di động thương mại đáp ứng tốt nhu cầu sử dụng liên tục trong các chuyến đi thông

thường.

Hiệu suất sử dụng CPU (%) và RAM (MB) của Raspberry Pi Zero 2W được

ghi nhận thông qua công cụ htop và quá trình theo dõi thực tế khi chạy các tác vụ

chính của hệ thống. Kết quả ghi nhận được thể hiện rõ qua hình 4-9. Cụ thể, khi hệ

thống ở chế độ chờ khởi động (Idle), mức sử dụng CPU duy trì ở mức thấp khoảng

8%, RAM sử dụng ổn định quanh mức 100 MB. Trong các giai đoạn xử lý yêu cầu

cao hơn như nhận diện hình ảnh và giám sát liên tục, mức sử dụng CPU dao động từ 35% đến 55%, trong khi RAM sử dụng ở mức từ 140 MB đến 160 MB. Khi thực hiện

các tác vụ cảnh báo và thực hiện cuộc gọi thông qua SIM900A, mức sử dụng tài

Trang 49

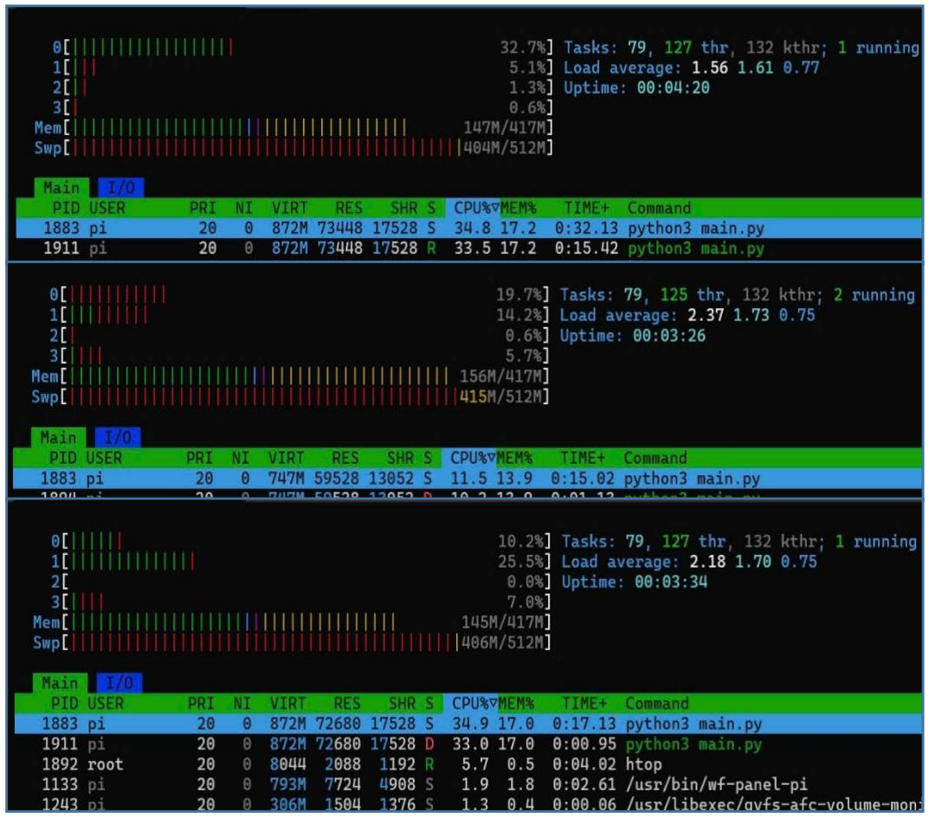
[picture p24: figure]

Thiết kế và phát triển mũ bảo hiểm IoT hỗ trợ giám sát an toàn giao thông và cảnh nguyên tăng cao hơn trong thời gian ngắn nhưng vẫn đảm bảo ổn định cho toàn hệ

thống.

Hình 4-9 Hiệu suất hoạt động của CPU&RAM của Raspberry Pi Zero 2W
Giá trị trung bình của mức sử dụng CPU và RAM trên Raspberry Pi Zero 2W được thống kê theo từng trạng thái hoạt động chính của hệ thống, bao gồm: chế độ

chờ khởi động, xử lý nhận diện hình ảnh, giám sát liên tục và thực hiện cảnh báo. Hình 4-9 minh họa mức sử dụng tài nguyên trung bình trong từng trạng thái, cho thấy

hệ thống hoạt động ổn định với mức tiêu thụ phần cứng không vượt quá giới hạn của

thiết bị. Trong khi đó, Hình 4-10 thể hiện diễn biến thay đổi của mức tiêu thụ CPU

và RAM theo thời gian trong quá trình vận hành thực tế. Biểu đồ phản ánh rõ sự dao

động tài nguyên tương ứng với các giai đoạn xử lý khác nhau, từ đó cho thấy tính ổn

định và khả năng thích ứng của hệ thống với các yêu cầu xử lý thời gian thực.

Đối với ESP32, mức sử dụng RAM heap dao động từ 40 KB khi ở chế độ chờ

đến khoảng 50 KB khi đồng thời nhận lệnh HTTP từ Raspberry Pi và thực hiện các

Trang 50

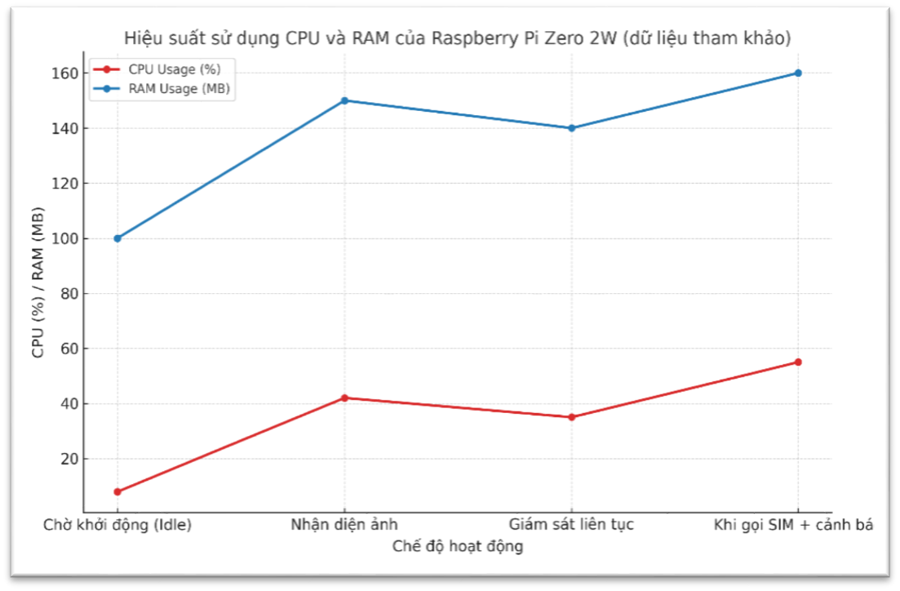
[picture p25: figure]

Thiết kế và phát triển mũ bảo hiểm IoT hỗ trợ giám sát an toàn giao thông và cảnh tác vụ như kích hoạt cảnh báo hoặc cuộc gọi khẩn cấp. Mức sử dụng bộ nhớ của

ESP32 phù hợp với giới hạn phần cứng và đảm bảo an toàn cho hoạt động lâu dài.

Hình 4-10 Biểu đồ sử dụng CPU và RAM của Raspberry Pi Zero 2W
Các kết quả trên cho thấy hệ thống sử dụng hợp lý tài nguyên phần cứng, đảm

bảo khả năng vận hành ổn định trong suốt quá trình hoạt động. Việc khai thác tài

nguyên không vượt quá ngưỡng cho phép của các thiết bị nhúng như Raspberry Pi

Zero 2W và ESP32, đồng thời vẫn đảm bảo đáp ứng tốt yêu cầu về thời gian thực cho

các tác vụ xử lý, nhận diện và cảnh báo. Điều này cũng mở ra tiềm năng cho việc mở

rộng hoặc tích hợp thêm các tính năng mới trong các phiên bản tiếp theo của hệ thống.

### 4.4 Một số hạn chế trong quá trình thi công

Trong quá trình nghiên cứu và triển khai thực tế hệ thống mũ bảo hiểm thông

minh IoT, bên cạnh những kết quả đạt được, nhóm thực hiện cũng ghi nhận một số

hạn chế và thách thức nhất định.

Trước hết, về phần cứng, việc lựa chọn Raspberry Pi Zero 2W làm bộ xử lý

trung tâm mang lại ưu điểm về kích thước nhỏ gọn và tiết kiệm năng lượng. Tuy

nhiên, với cấu hình phần cứng hạn chế (CPU ARM Cortex-A53, RAM 512 MB), hiệu

Trang 51

Thiết kế và phát triển mũ bảo hiểm IoT hỗ trợ giám sát an toàn giao thông và cảnh suất xử lý của mô hình học sâu MobileNet SSD chỉ đạt khoảng 2.5–3 FPS. Điều này

chưa đủ để đáp ứng yêu cầu nhận diện hình ảnh ở tốc độ cao khi xe di chuyển nhanh

hoặc trong các môi trường có điều kiện ánh sáng phức tạp.

Trong các thử nghiệm thực tế, nhóm nhận thấy độ chính xác của thuật toán

nhận diện ảnh bị ảnh hưởng đáng kể bởi điều kiện môi trường, đặc biệt là ánh sáng

yếu hoặc ban đêm. Độ chính xác trong các điều kiện này dao động từ 40% đến 60%,

có thể dẫn đến các trường hợp cảnh báo sai hoặc từ chối khởi động xe dù người điều

khiển đã đội mũ đúng cách. Đây là điểm cần được cải thiện thông qua việc huấn luyện

thêm dữ liệu trong các môi trường ánh sáng khác nhau.

Hệ thống cảm biến lực mặc dù hoạt động ổn định trong môi trường thử nghiệm,

nhưng trong thực tế, kết quả đo có thể bị ảnh hưởng bởi cách đội mũ hoặc bởi lực

phân bố không đồng đều trên đầu người dùng. Điều này có thể gây ra các cảnh báo

sai, làm ảnh hưởng đến trải nghiệm của người dùng.

Ngoài ra, trong quá trình vận hành tại các khu vực có sóng di động yếu, thời

gian gửi cảnh báo khẩn cấp qua cuộc gọi hoặc tin nhắn có thể tăng lên trên 10 giây

hoặc có thể không bắt sóng được, ảnh hưởng đến khả năng hỗ trợ kịp thời khi xảy ra

sự cố. Việc tối ưu hóa cơ chế gửi cảnh báo khẩn cấp trong các môi trường mạng yếu

cần được tiếp tục nghiên cứu.

Về phần mềm, mặc dù mô hình Random Forest sử dụng cho phân tích hành vi

từ dữ liệu cảm biến MPU6050 cho độ chính xác cao trên tập dữ liệu hiện tại, tuy nhiên

mô hình chưa được tinh chỉnh cho các phong cách lái xe đa dạng hoặc các tình huống

hiếm gặp, điều này có thể làm giảm độ chính xác trong một số trường hợp đặc biệt.

Cuối cùng, hệ thống hiện tại chưa hỗ trợ cơ chế cập nhật phần mềm từ xa (OTA).

Việc nâng cấp phần mềm trên Raspberry Pi và ESP32 vẫn thực hiện thủ công, gây

khó khăn khi cần triển khai các bản cập nhật hoặc sửa lỗi sau khi hệ thống đã được

lắp đặt trên thiết bị thật.

Trang 52

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

CHƯƠNG 5. KẾT LUẬN VÀ HƯỚNG PHÁT TRIỂN
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

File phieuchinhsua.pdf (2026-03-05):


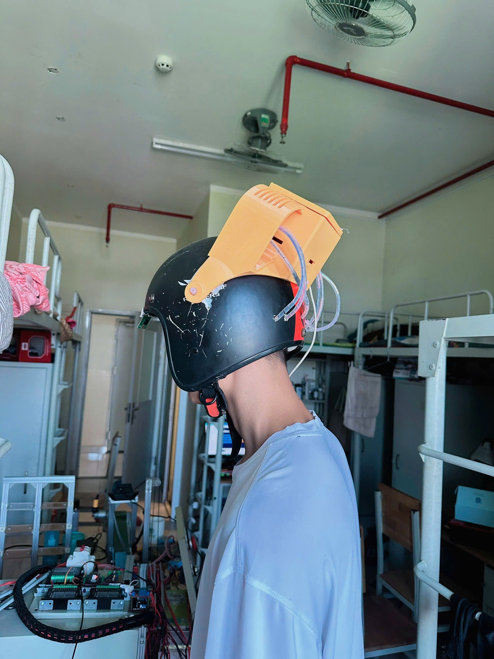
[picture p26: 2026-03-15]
img/z7623570571412_343feccadeb8f163133e0a017ed94bd8.jpg

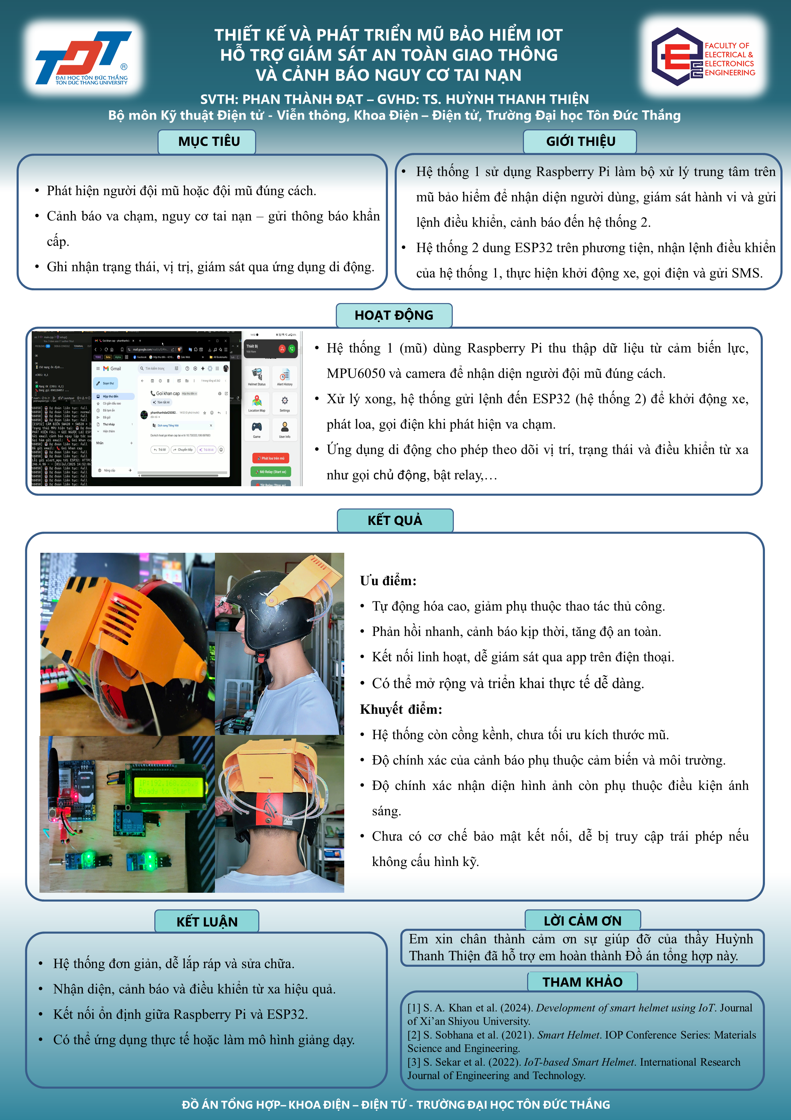
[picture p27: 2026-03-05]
Slide1.PNG

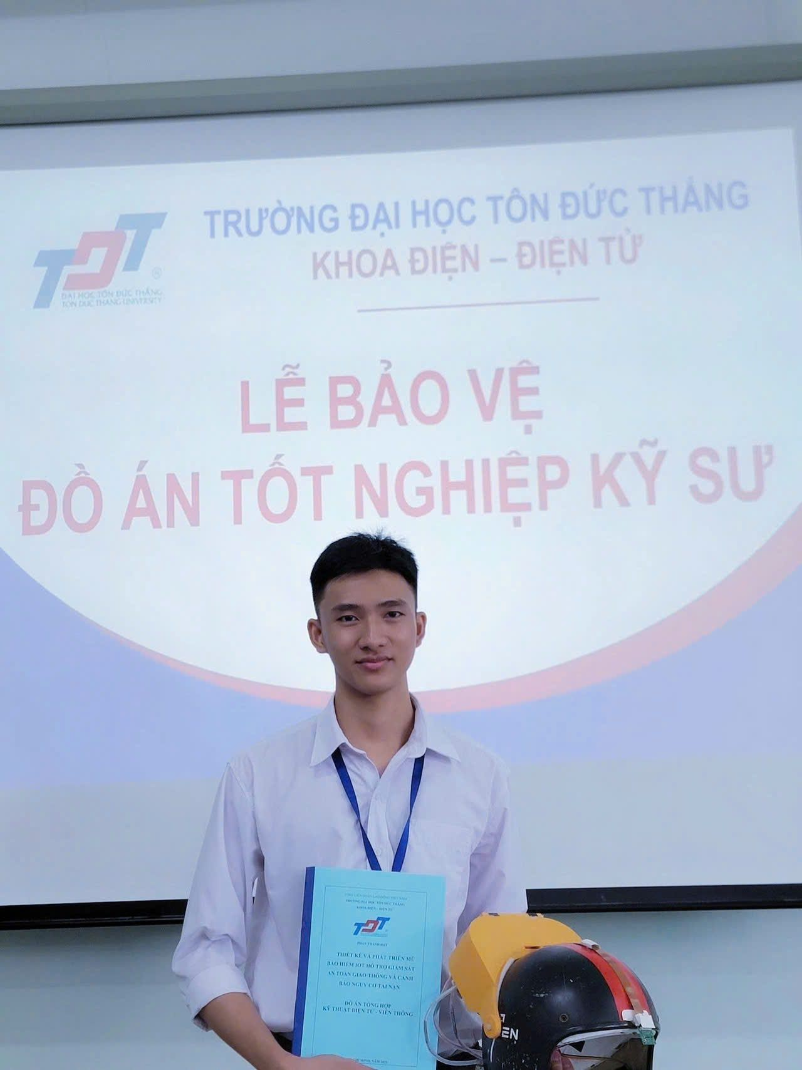
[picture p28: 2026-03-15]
img/z7623570574121_5c18436ab208715bd783d2d72c90966b.jpg

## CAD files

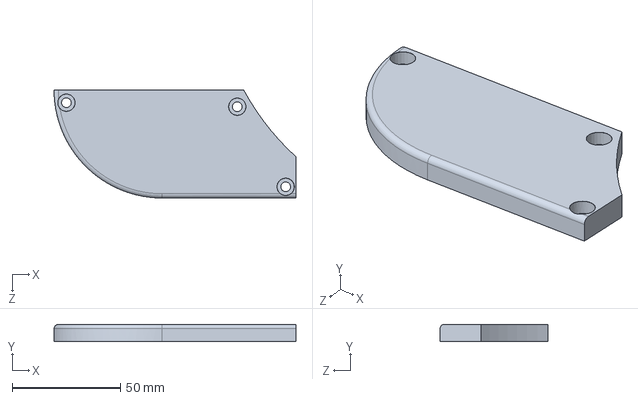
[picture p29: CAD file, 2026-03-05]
Nắp phai.SLDPRT
112.0 x 8.00 x 50.0 mm

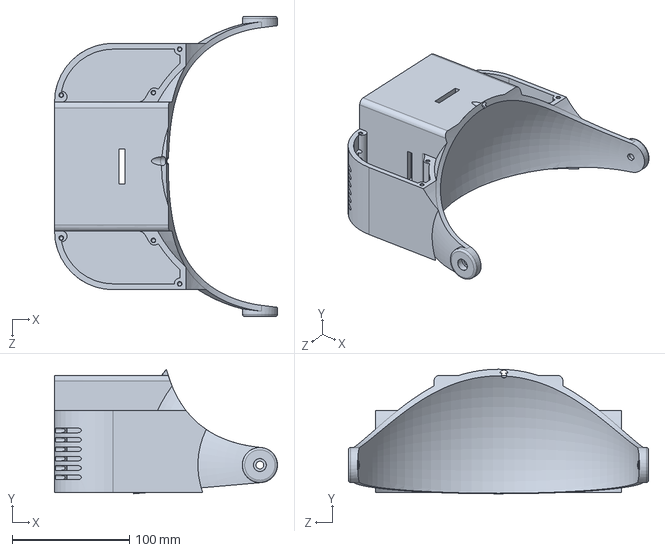
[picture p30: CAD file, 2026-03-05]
hộp nón 2 (1).SLDPRT
190.0 x 106.1 x 256.0 mm

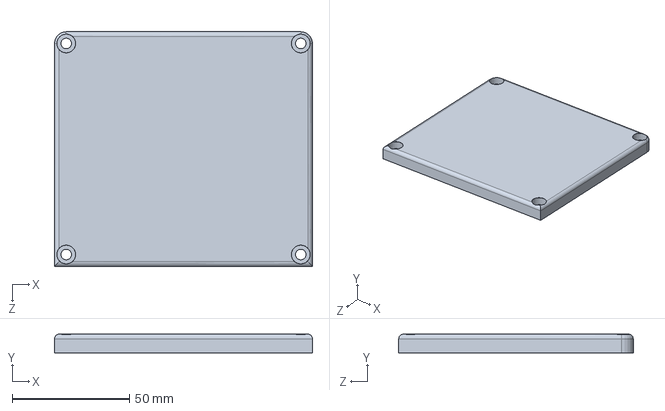
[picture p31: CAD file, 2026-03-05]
Nắp giữa.SLDPRT
110.0 x 8.00 x 100.0 mm

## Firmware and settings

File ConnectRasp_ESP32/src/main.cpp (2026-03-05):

#include <WiFi.h>
#include <HTTPClient.h>
#include <WebServer.h>
#include <HardwareSerial.h>
#include <Wire.h>
#include <LiquidCrystal_I2C.h>

TaskHandle_t CallTaskHandle = NULL;
portMUX_TYPE uartMux = portMUX_INITIALIZER_UNLOCKED;

const char* ssid = "DACN";
const char* password = "12345678";

const char* pi_ip_url = "https://script.google.com/macros/s/AKfycbxazIeUl2Q9zXUBUVG-kuc6q9RA7jbuqJPFwdN6oaU8IDeOWHtLo74hR4Kkd9XpcNDT/exec";
const char* scriptURL = "https://script.google.com/macros/s/AKfycbzyYU-wogDP8d2snAJm4yRgYTDyovdMoSeKtGnVtBiEgNwbn8JAIRiAcpXDDhpD2m2K/exec";

#define RELAY_PIN 15
#define SW420_PIN 25
#define SW520_PIN 26
#define SIM_TX 17
#define SIM_RX 16

LiquidCrystal_I2C lcd(0x27, 16, 2);  // LCD I2C 16x2

HardwareSerial SIM900(1);
WebServer server(80);
bool isCalling = false;
unsigned long activateStart = 0;
bool counting = false;
String pi_ip = "";
String phoneNumber = "0901284053";

void showSIMResponse() {
  portENTER_CRITICAL(&uartMux);
  while (SIM900.available()) {
    char c = SIM900.read();
    Serial.write(c);
  }
  portEXIT_CRITICAL(&uartMux);
}

bool checkNetworkReady() {
  for (int i = 0; i < 5; i++) {
    portENTER_CRITICAL(&uartMux);
    SIM900.println("AT+CREG?");
    portEXIT_CRITICAL(&uartMux);
    delay(500);
    String response = "";

    portENTER_CRITICAL(&uartMux);
    while (SIM900.available()) {
      char c = SIM900.read();
      response += c;
      Serial.write(c);
    }
    portEXIT_CRITICAL(&uartMux);

    if (response.indexOf("+CREG: 0,1") >= 0) {
      Serial.println("✅ Mạng OK (CREG: 0,1)");
      return true;
    } else {
      Serial.println("⚠️ Mạng chưa sẵn sàng, thử lại...");
      delay(2000);
    }
  }
  Serial.println("❌ Mạng không sẵn sàng sau 5 lần thử!");
  return false;
}

void notifyPiCallDone();

void callPhoneNumber() {
  if (isCalling) {
    Serial.println("🚫 Đang trong cuộc gọi, bỏ qua callPhoneNumber!");
    return;
  }

  isCalling = true;
  Serial.println("📞 Bắt đầu gọi SIM900A...");

  server.stop();
  delay(100);

  portENTER_CRITICAL(&uartMux);
  SIM900.println("ATZ");
  portEXIT_CRITICAL(&uartMux);
  delay(500);
  showSIMResponse();

  portENTER_CRITICAL(&uartMux);
  SIM900.println("ATE0");
  portEXIT_CRITICAL(&uartMux);
  delay(500);
  showSIMResponse();

  portENTER_CRITICAL(&uartMux);
  SIM900.println("AT+CSQ");
  portEXIT_CRITICAL(&uartMux);
  delay(500);
  showSIMResponse();

  portENTER_CRITICAL(&uartMux);
  SIM900.println("AT+CPIN?");
  portEXIT_CRITICAL(&uartMux);
  delay(500);
  showSIMResponse();

  portENTER_CRITICAL(&uartMux);
  SIM900.println("AT+CREG?");
  portEXIT_CRITICAL(&uartMux);
  delay(500);
  showSIMResponse();

  portENTER_CRITICAL(&uartMux);
  SIM900.println("AT+COPS?");
  portEXIT_CRITICAL(&uartMux);
  delay(1000);
  showSIMResponse();

  portENTER_CRITICAL(&uartMux);
  SIM900.println("AT+COLP=1");
  portEXIT_CRITICAL(&uartMux);
  delay(500);
  showSIMResponse();

  portENTER_CRITICAL(&uartMux);
  SIM900.println("AT+CSCS=\"GSM\"");
  portEXIT_CRITICAL(&uartMux);
  delay(500);
  showSIMResponse();

  Serial.println("⏳ Chờ mạng ổn định...");

  if (!checkNetworkReady()) {
    Serial.println("❌ Hủy cuộc gọi vì không có mạng!");
    return;
  }

  String cmd = "ATD" + phoneNumber + ";";
  delay(1000);
  portENTER_CRITICAL(&uartMux);
  SIM900.println(cmd);
  portEXIT_CRITICAL(&uartMux);

  Serial.printf("📞 Đang gọi %s ...\n", phoneNumber.c_str());

  for (int i = 0; i < 60; i++) {
    showSIMResponse();
    delay(500);
  }

  portENTER_CRITICAL(&uartMux);
  SIM900.println("ATH");
  portEXIT_CRITICAL(&uartMux);
  Serial.println("📞 Đã cúp máy.");
  delay(1000);
  showSIMResponse();
  notifyPiCallDone();

  isCalling = false;
  server.begin();
  CallTaskHandle = NULL;
  Serial.println("🌐 WebServer đã khởi động lại.");
}

void CallTask(void *parameter) {
  Serial.println("📡 Tắt WiFi để gọi SIM900A...");
  WiFi.disconnect(true);
  WiFi.mode(WIFI_OFF);
  delay(500);

  callPhoneNumber();

  Serial.println("📡 Bật lại WiFi sau khi gọi...");
  WiFi.mode(WIFI_STA);
  WiFi.begin(ssid, password);

  while (WiFi.status() != WL_CONNECTED) {
    delay(500);
    Serial.print(".");
  }

  Serial.println("\n✅ WiFi đã kết nối lại.");
  server.begin();

  CallTaskHandle = NULL;
  vTaskDelete(NULL);
}

void sendIPtoGoogleSheet(const String& ip) {
  HTTPClient http;
  String url = String(scriptURL) + "?ip=" + ip;
  http.begin(url);
  http.setFollowRedirects(HTTPC_STRICT_FOLLOW_REDIRECTS);
  int httpCode = http.GET();
  if (httpCode > 0) {
    Serial.printf("HTTP Response code: %d\n", httpCode);
    Serial.println(http.getString());
  } else {
    Serial.printf("Lỗi gửi IP: %s\n", http.errorToString(httpCode).c_str());
  }
  http.end();
}

void notifyPiCallDone() {
  if (pi_ip == "") return;
  HTTPClient http;
  String url = "http://" + pi_ip + ":5000/log_call_done";
  http.begin(url);
  int httpCode = http.POST("");
  if (httpCode > 0) {
    Serial.printf("📞 Đã báo log_call_done về Pi (%d)\n", httpCode);
  } else {
    Serial.printf("❌ Lỗi gửi log_call_done: %s\n", http.errorToString(httpCode).c_str());
  }
  http.end();
}

void handleRelay() {
  String state = server.arg("state");
  if (state == "on") {
    digitalWrite(RELAY_PIN, HIGH);
    server.send(200, "text/plain", "Relay ON");
  } else if (state == "off") {
    digitalWrite(RELAY_PIN, LOW);
    server.send(200, "text/plain", "Relay OFF");
  } else {
    server.send(400, "text/plain", "Tham số không hợp lệ. Dùng ?state=on hoặc off");
  }
}

void sendAlertToPi() {
  if (pi_ip == "") {
    Serial.println("❌ Không có IP Pi!");
    return;
  }
  HTTPClient http;
  String url = "http://" + pi_ip + ":5000/alert_sw";
  http.begin(url);
  int httpCode = http.POST("");
  if (httpCode > 0) {
    Serial.printf("📡 Gửi cảnh báo về Pi %s, Response: %d\n", pi_ip.c_str(), httpCode);
    Serial.println(http.getString());
  } else {
    Serial.printf("❌ Lỗi gửi cảnh báo: %s\n", http.errorToString(httpCode).c_str());
  }
  http.end();
}

void checkSensors() {
  int sw420 = digitalRead(SW420_PIN);
  int sw520 = digitalRead(SW520_PIN);

  if (sw420 == LOW && sw520 == LOW) {
    if (!counting) {
      counting = true;
      activateStart = millis();
      Serial.println("⏳ Cả 2 cảm biến ON → Bắt đầu đếm 3 giây...");
    } else {
      if (millis() - activateStart >= 3000) {
        Serial.println("🚨 Cảm biến SW420 + SW520 > 3s → Gửi cảnh báo về Pi!");
        sendAlertToPi();
        counting = false;
        delay(7000);
      }
    }
  } else {
    counting = false;
  }
}

void getPiIP() {
  HTTPClient http;
  http.begin(pi_ip_url);
  http.setFollowRedirects(HTTPC_STRICT_FOLLOW_REDIRECTS);
  int httpCode = http.GET();
  if (httpCode > 0) {
    String ip = http.getString();
    ip.trim();
    Serial.printf("🌐 Pi IP mới nhất: %s\n", ip.c_str());
    pi_ip = ip;
  } else {
    Serial.printf("❌ Lỗi lấy IP Pi: %s\n", http.errorToString(httpCode).c_str());
  }
  http.end();
}

void handleAlertMPU() {
  Serial.println("🚨 Nhận yêu cầu ALERT_MPU từ Pi → tạo Task gọi SIM900A!");
  if (isCalling) {
    Serial.println("🚫 Đang trong cuộc gọi → từ chối ALERT_MPU");
    server.send(200, "text/plain", "BUSY - Đang trong cuộc gọi SIM900A");
    return;
  }

  if (CallTaskHandle == NULL) {
    xTaskCreatePinnedToCore(CallTask, "CallTask", 4096, NULL, 1, &CallTaskHandle, 0);
    server.send(200, "text/plain", "CONFIRM_ACCIDENT");
  } else {
    server.send(200, "text/plain", "BUSY - Đang gọi SIM900A");
  }
}

void handleSetPhone() {
  String newPhone = server.arg("phone");
  if (newPhone.length() > 5) {
    phoneNumber = newPhone;
    Serial.printf("✅ Đã cập nhật số điện thoại mới: %s\n", phoneNumber.c_str());
    server.send(200, "text/plain", "Phone updated");
  } else {
    server.send(400, "text/plain", "Invalid phone number");
  }
}
void handleSendSMS() {
  String msg = server.arg("msg");
  if (msg.length() == 0) {
    server.send(400, "text/plain", "Thiếu tham số msg");
    return;
  }

  if (!checkNetworkReady()) {
    server.send(500, "text/plain", "SIM900A không có mạng!");
    return;
  }

  String cmd = "AT+CMGF=1";  // Text mode
  SIM900.println(cmd);
  delay(500);
  showSIMResponse();

  cmd = "AT+CMGS=\"" + phoneNumber + "\"";
  SIM900.println(cmd);
  delay(500);
  showSIMResponse();

  SIM900.print(msg);
  SIM900.write(26); // Ctrl+Z để gửi
  delay(1000);
  showSIMResponse();

  server.send(200, "text/plain", "SEND SMS");
}

void setup() {
  Serial.begin(9600);
  SIM900.begin(9600, SERIAL_8N1, SIM_RX, SIM_TX);

  pinMode(RELAY_PIN, OUTPUT);
  digitalWrite(RELAY_PIN, LOW);
  pinMode(SW420_PIN, INPUT_PULLUP);
  pinMode(SW520_PIN, INPUT_PULLUP);

  Wire.begin(21, 22);
  lcd.init();
  lcd.backlight();
  lcd.clear();
  lcd.setCursor(0, 0);
  lcd.print("WiFi Connecting...");

  WiFi.begin(ssid, password);
  Serial.print("Đang kết nối WiFi");
  while (WiFi.status() != WL_CONNECTED) {
    delay(500);
    Serial.print(".");
  }

  Serial.println("\n✅ Đã kết nối WiFi");
  String ip = WiFi.localIP().toString();
  Serial.print("🌐 IP nội bộ ESP32: ");
  Serial.println(ip);

  sendIPtoGoogleSheet(ip);
  getPiIP();

  lcd.clear();
  lcd.setCursor(0, 0);
  lcd.print("IP:");
  lcd.print(ip);
  lcd.setCursor(0, 1);
  lcd.print("Ready to Start");
  server.on("/send_sms", handleSendSMS);
  server.on("/relay", handleRelay);
  server.on("/alert_mpu", handleAlertMPU);
  server.on("/set_phone", handleSetPhone);
  server.begin();
  Serial.println("🌐 WebServer đã sẵn sàng (port 80)");
}

unsigned long lastGetPiIP = 0;
const unsigned long getPiInterval = 2 * 60 * 5000;

void loop() {
  server.handleClient();
  checkSensors();

  if (millis() - lastGetPiIP > getPiInterval) {
    getPiIP();
    lastGetPiIP = millis();
  }

  delay(50);
}

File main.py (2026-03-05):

import warnings
warnings.filterwarnings("ignore", category=UserWarning)
import numpy as np
import pandas as pd
import tflite_runtime.interpreter as tflite
from PIL import Image, ImageEnhance
import os
import time
import board
import busio
import RPi.GPIO as GPIO
import requests
import socket
import smbus2
import joblib
from datetime import datetime
from threading import Thread
from flask import Flask, request
from adafruit_ads1x15.analog_in import AnalogIn
import adafruit_ads1x15.ads1115 as ADS
from google.oauth2 import service_account
from googleapiclient.discovery import build
import smtplib
from email.mime.text import MIMEText
from email.mime.multipart import MIMEMultipart
from datetime import datetime, timedelta
last_call_time = datetime.min  # thời gian lần gọi gần nhất
def send_emergency_email(subject, body):
    try:
        print("🧪 Gọi hàm gửi email: ", subject)
        msg = MIMEMultipart()
        msg['From'] = EMAIL_SENDER
        msg['To'] = EMAIL_RECEIVER
        msg['Subject'] = subject

        msg.attach(MIMEText(body, 'plain'))

        server = smtplib.SMTP_SSL('smtp.gmail.com', 465)
        server.login(EMAIL_SENDER, EMAIL_PASSWORD)
        server.sendmail(EMAIL_SENDER, EMAIL_RECEIVER, msg.as_string())
        server.quit()

        print("📧 Đã gửi email:", subject)
    except Exception as e:
        print(f"❌ Gửi email thất bại: {e}")

last_alarm_time = datetime.min  # 🆕 thời điểm báo động cuối
# === Google Sheets Config ===
SPREADSHEET_ID = '1rOX2ULAQ4fAMfDijPcDynpaQx-rwwhKBXyNRi89T58o'
CREDENTIALS_FILE = 'credentials.json'
# ==== email ===
EMAIL_SENDER = "phanthanhdat25082003@gmail.com"
EMAIL_PASSWORD = "qwafdvecgpdnfelj"
EMAIL_RECEIVER = "phanthanhdat0825@gmail.com"
creds = service_account.Credentials.from_service_account_file(
    CREDENTIALS_FILE,
    scopes=['https://www.googleapis.com/auth/spreadsheets']
)
sheet_service = build('sheets', 'v4', credentials=creds)

# === GPIO Config ===
BUZZER_PIN = 27
HALL_PIN = 22
GPIO.setmode(GPIO.BCM)
GPIO.setup(HALL_PIN, GPIO.IN, pull_up_down=GPIO.PUD_UP)
GPIO.setup(BUZZER_PIN, GPIO.OUT)

# === ADC for force sensors ===
i2c = busio.I2C(board.SCL, board.SDA)
ads = ADS.ADS1115(i2c)
force_top = AnalogIn(ads, ADS.P0)
force_forehead = AnalogIn(ads, ADS.P2)
force_left = AnalogIn(ads, ADS.P1)   # A1 bên trái
force_right = AnalogIn(ads, ADS.P3)  # A3 bên phải
FORCE_THRESHOLD = 2000

# === Load label and TFLite model ===
with open("labelmap.txt", "r") as f:
    labels = f.read().splitlines()

interpreter = tflite.Interpreter(model_path="model.tflite")
interpreter.allocate_tensors()
input_details = interpreter.get_input_details()
output_details = interpreter.get_output_details()
input_height = input_details[0]['shape'][1]
input_width = input_details[0]['shape'][2]

# === Load sklearn model ===
bus = smbus2.SMBus(1)
MPU6050_ADDR = 0x68
model = joblib.load("mpu6050_rf_model.pkl")
ENABLE_FORCE = True
ENABLE_MPU = True
ENABLE_HALL = True

def init_mpu():
    bus.write_byte_data(MPU6050_ADDR, 0x6B, 0)
    time.sleep(0.1)

def read_raw_data(addr):
    high = bus.read_byte_data(MPU6050_ADDR, addr)
    low = bus.read_byte_data(MPU6050_ADDR, addr+1)
    value = ((high << 8) | low)
    if value > 32768:
        value = value - 65536
    return value

def read_mpu6050():
    ax = read_raw_data(0x3B) / 16384.0
    ay = read_raw_data(0x3D) / 16384.0
    az = read_raw_data(0x3F) / 16384.0
    gx = read_raw_data(0x43) / 131.0
    gy = read_raw_data(0x45) / 131.0
    gz = read_raw_data(0x47) / 131.0
    return ax, ay, az, gx, gy, gz

def predict_behavior(ax, ay, az, gx, gy, gz):
    input_data = pd.DataFrame([[ax, ay, az, gx, gy, gz]],
                              columns=["ax", "ay", "az", "gx", "gy", "gz"])
    return model.predict(input_data)[0]

def get_latest_ip():
    try:
        result = sheet_service.spreadsheets().values().get(
            spreadsheetId=SPREADSHEET_ID,
            range="Main!A2:M"
        ).execute()
        values = result.get('values', [])
        if values:
            return values[-1][1]
    except Exception as e:
        print("❌ Lỗi đọc IP từ Google Sheets:", e)
    return None

def get_pi_ip():
    try:
        s = socket.socket(socket.AF_INET, socket.SOCK_DGRAM)
        s.connect(("8.8.8.8", 80))
        ip = s.getsockname()[0]
        s.close()
        return ip
    except:
        return "Unknown"

        
def append_status_to_sheet(detect1, detect2, detect3, conclusion,
                           accident_flag=0,
                           detection_source='',
                           esp_response='',
                           gps_location='',
                           note=''):
    try:
        current_time = datetime.now().strftime('%H:%M:%S')
        current_date = datetime.now().strftime('%d/%m/%Y %H:%M:%S')
        esp_ip = get_latest_ip() or ''
        pi_ip = get_pi_ip()

        body = {
            'values': [[
                current_date, esp_ip, pi_ip, current_time,
                detect1, detect2, detect3, conclusion,
                accident_flag, detection_source, esp_response,
                gps_location, note
            ]]
        }
        sheet_service.spreadsheets().values().append(
            spreadsheetId=SPREADSHEET_ID,
            range="Main!A2",
            valueInputOption="USER_ENTERED",
            body=body
        ).execute()
        print("✅ Đã ghi trạng thái + tai nạn lên Google Sheets.")
    except Exception as e:
        print("⚠️ Lỗi ghi Google Sheets:", e)


def upload_pi_ip_only():
    try:
        current_date = datetime.now().strftime('%d/%m/%Y %H:%M:%S')
        pi_ip = get_pi_ip()

        body = {
            'values': [[
                current_date, pi_ip
            ]]
        }
        sheet_service.spreadsheets().values().append(
            spreadsheetId=SPREADSHEET_ID,
            range="RaspberryIP!A1",  # 🚀 Sheet mới tên RaspberryIP
            valueInputOption="USER_ENTERED",
            insertDataOption="INSERT_ROWS",  # luôn chèn dòng mới
            body=body
        ).execute()
        print(f"✅ Đã ghi Pi IP lên Sheet RaspberryIP: {pi_ip}")
    except Exception as e:
        print("⚠️ Lỗi khi ghi Pi IP:", e)

def auto_upload_pi_ip():
    upload_pi_ip_only()  # 🚀 Ghi 1 lần duy nhất khi khởi động
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

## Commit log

2026-03-05 run for ESP32
2026-03-05 main for Raspberry
